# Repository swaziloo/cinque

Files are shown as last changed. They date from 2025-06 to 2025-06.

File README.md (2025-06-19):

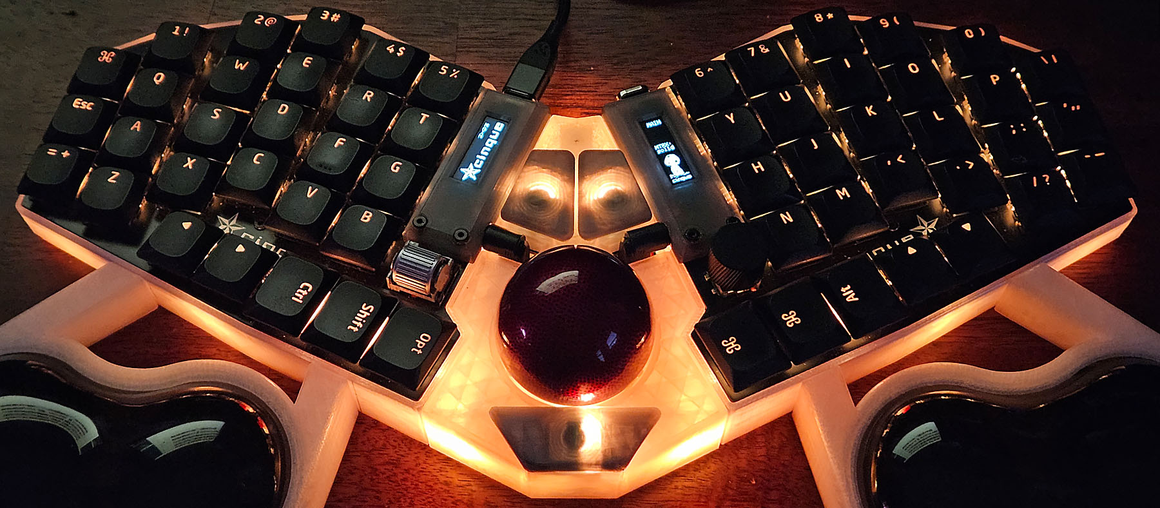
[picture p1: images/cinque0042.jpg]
cinique keyboard with trackball

# cinque 
### (\[ˈt͡ʃin.kwe\] or \[sĭngk\], your choice)
cinque is an open-source 56-key compact columnar staggered low-profile split 
mechanical keyboard and trackball with RGB lighting and rotary encoders
designed in [Ergogen](https://ergogen.xyz/)
laid out in [KiCad](https://www.kicad.org/)
with cases modeled in [FreeCAD](https://www.freecad.org/)
and driven by [QMK](https://qmk.fm/)
or [ZMK](https://zmk.dev/)
firmware. 
The project was inspired by (and borrows *heavily* from) the
[Corax](https://github.com/dnlbauer/corax-keyboard), 
[Atreus](https://atreus.technomancy.us/),
[Sofle](https://josefadamcik.github.io/SofleKeyboard/) and 
[Lily58](https://github.com/kata0510/Lily58) projects
and features footprints designed or inspired by [ceoloide](https://github.com/ceoloide/ergogen-footprints),
[infused-kim](https://github.com/infused-kim/kb_ergogen_fp),
and [dnlbauer](https://github.com/dnlbauer/corax-keyboard/tree/main/corax56/ergogen/footprints)

### Hardware
cinque is built around paired ProMicro controllers,
employing RP2040 (for wired, trackball, RGB, OLED)
or NRF52840 (for battery, Bluetooth, Nice!Nano).
Other MCUs and configurations are viable.
- **Switches:** Gateron KS-33 low-profile (MX stem) hot-swap
- **Rotary:** EC11 or Panasonic EVQWGD001 (horizontal) per side
- **Trackball:** PMW3389 module and Gateron KS-33 switches 
- **RGB:** SK6812 per-key and 3535 underglow lights (including trackball)
- **Display:** 0.91" I2C OLED or Nice!View (low-power) LCD (via custom footprint)

### Firmware
- [QMK](qmk/cinque/README.md) (for RP2040) including [my keymap](https://github.com/swaziloo/cinque/blob/main/qmk/cinque/CinqueKeymapQMK-01.pdf)
- [ZMK](https://github.com/swaziloo/cinque-zmk-config) (for NRF52840) including [my (very similar) keymap](https://github.com/swaziloo/cinque-zmk-config/blob/main/CinqueKeymapZMK-01.pdf)

Note that the firmware folders also include an [SVG template](https://github.com/swaziloo/cinque/blob/main/qmk/cinque/CinqueLayout01.svg) in case you want to lay out your own keymaps.

### [Build Guide](build.md)

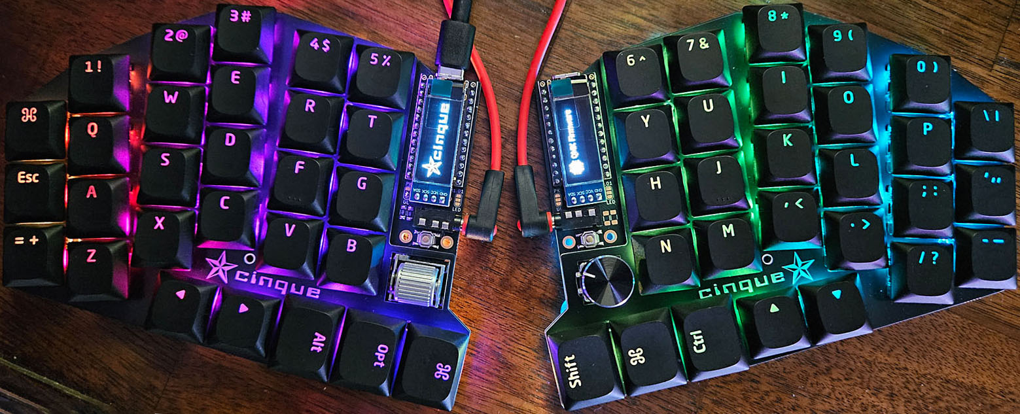
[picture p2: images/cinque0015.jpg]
cinque keyboard RGB Test


### [The Story](story.md)

### Versions
**1.0:**
The initial one-sided version (202410) is intended to enable a large number of possible features
and configurations.
- The EC11 switch plate cutout is too small and requires filing to accommodate the board connectors (fixed 1.1)
- NRF52840 P1.01 Nice!View CS pin option is untested
- I2C split communication is untested
- Right-side FPC (trackball) is untested

**1.1:**
(switch plate only at this time&mdash;202506)
Adds 1.25x8mm and 1.5x8mm side expansions to accommodate the EC11 connectors on the cutout.

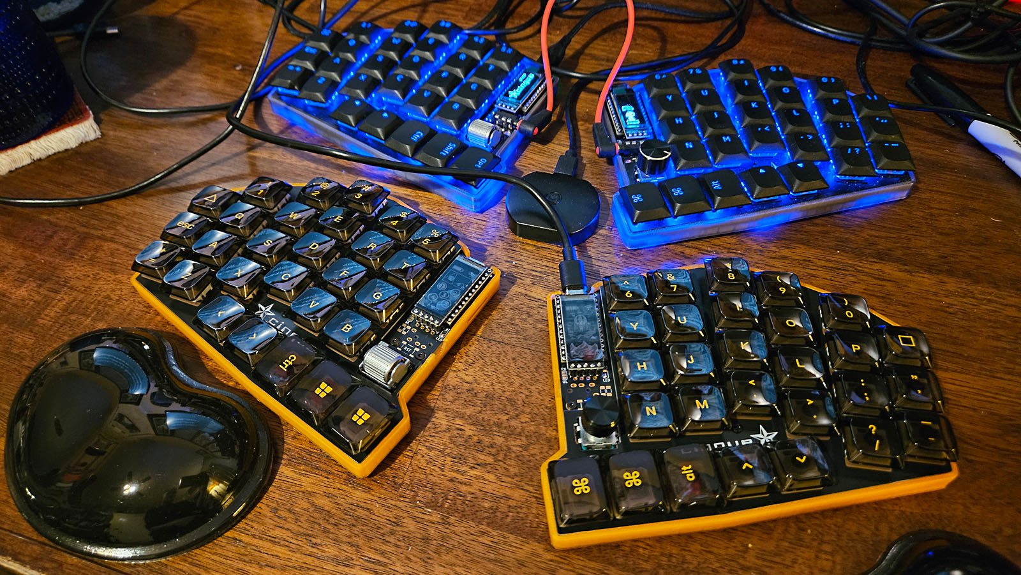
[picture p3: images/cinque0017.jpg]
cinque in minimal cases


### Future Development
- Move/change TRRS
- Large battery single side charge via Schottky diode(?) and shared power switch 
- Trackball with mouse (small) switches
- 34mm trackball (maybe)
- Kailh Choc, Cherry MX, (or other switch?) version
- Consider central (on board?) controller(s) with connected peripherals
- Find or design a horizontal encoder replacement for the Panasonic

cinque is licensed under an [MIT license](LICENSE).

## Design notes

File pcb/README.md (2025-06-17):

# cinque PCB 
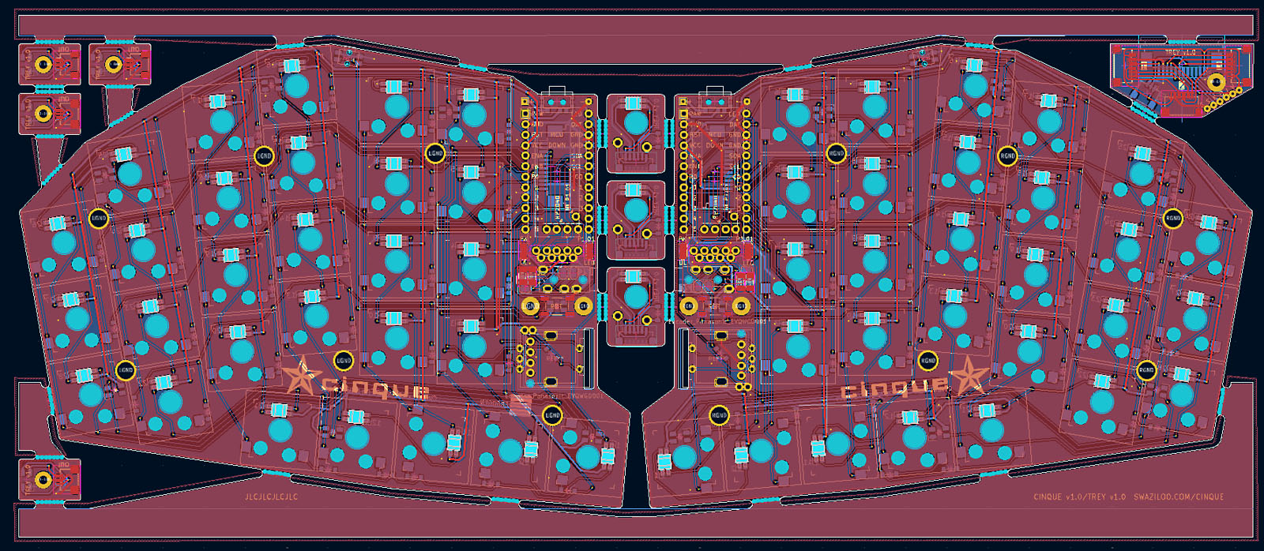
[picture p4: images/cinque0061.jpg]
cinque KiCad pcb


cinque was laid out by hand in [KiCad](https://www.kicad.org/) 8.0.8 from the Ergogen output files.

A single PCB panel will make a keyboard and trackball.

Gerber files were exported according to instructions from [JLCPCB](https://jlcpcb.com/help/article/how-to-generate-gerber-and-drill-files-in-kicad-8).

Let me know if something (footprint library?) doesn't come through, as I haven't previously exported KiCad files.

## cinque Switch Plate
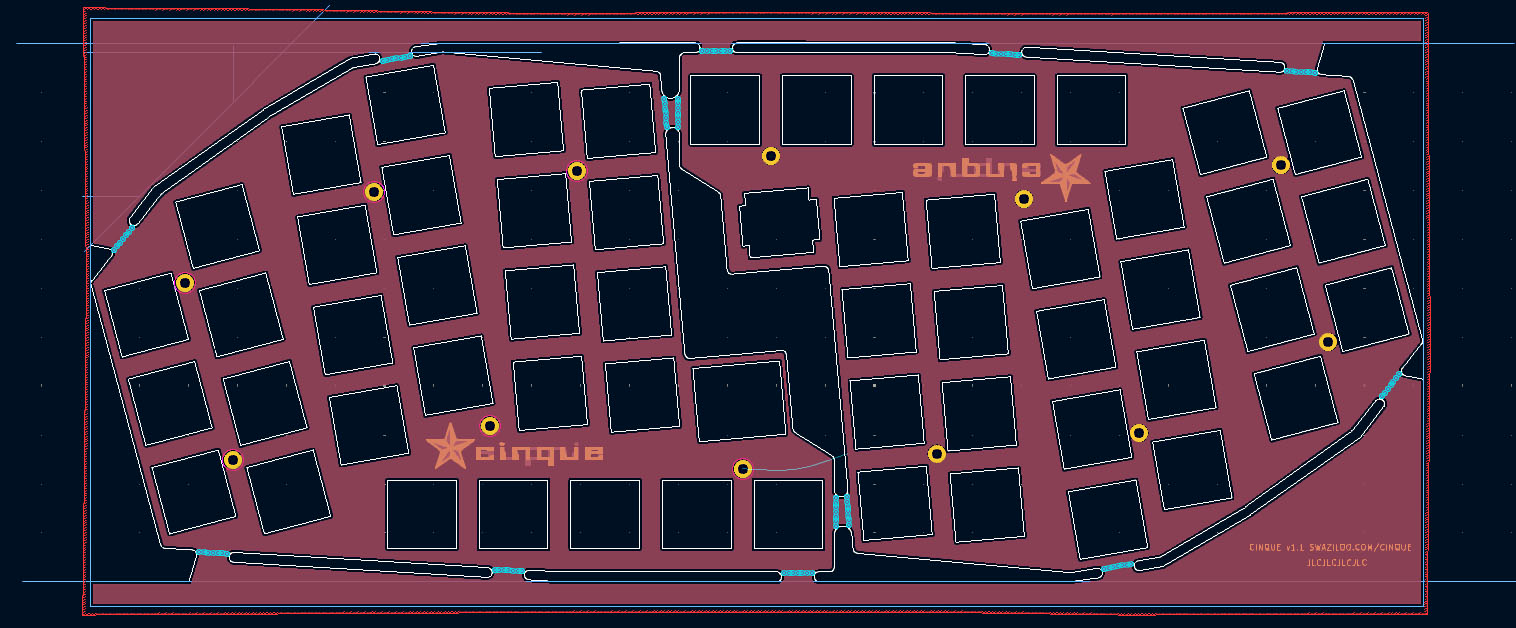
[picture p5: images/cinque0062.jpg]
cinque KiCad pcb

A single switch plate panel provides one EC11 and one EVQWGD001 cutout. These are reversible and can go on either side.

> **Note:** I have extra switch plates available with HASL finish.

## cinque Base Plate

There is no design or files for a base plate at this time (though one could be added.)

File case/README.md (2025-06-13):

# cinque Case Files
cinque cases are designed and drafted in [FreeCAD](https://www.freecad.org/) 1.0.1
with the intention of being produced on a 3D printer.
Add supports where needed.

stl files can be previewed, measured, and inspected in the [ONLINE 3D VIEWER](https://3dviewer.net/)

| | |
|---|---|
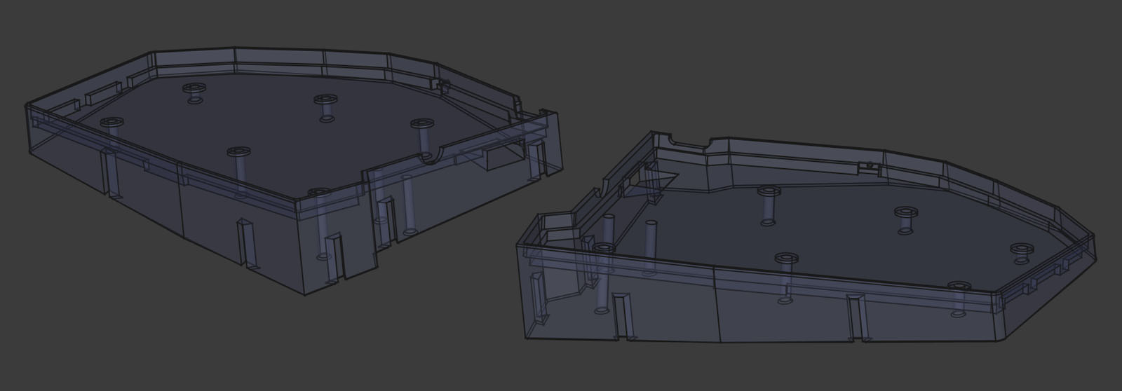
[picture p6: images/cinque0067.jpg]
cinque ergogen outlines
|  | v1.0 22mm negative tilt for wired boards. Print right-side up. |
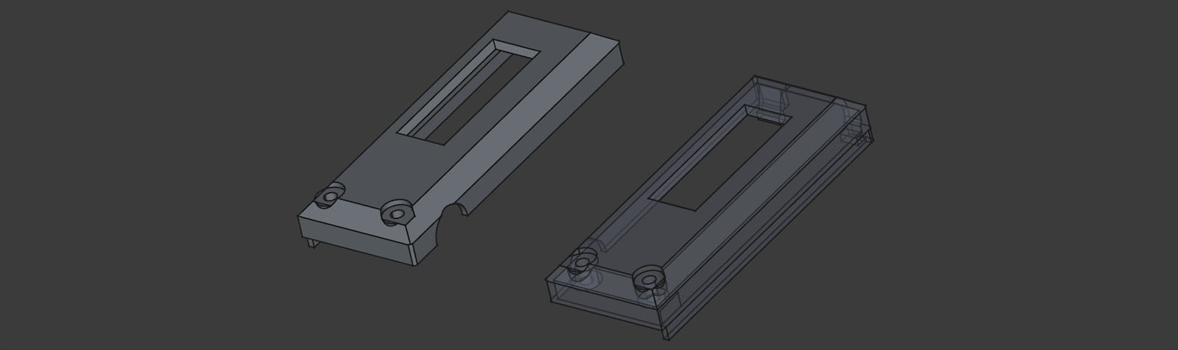
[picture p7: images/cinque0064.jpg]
cinque ergogen outlines
|  | v1.0 covers for OLED displays (use 5mm m2 standoffs). Print upside-down. |
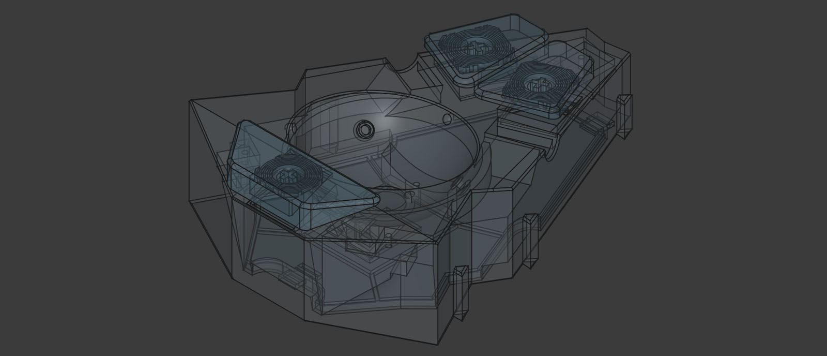
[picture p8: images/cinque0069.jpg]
cinque ergogen outlines
|  | v1.0 trackball with keycaps and base cover. Print housing upside-down with supports. Print keycaps with the stem turned 45-degrees upwards and enough supports to handle the keys tilted on their edge. Print cover right-side up with suports for tabs. |
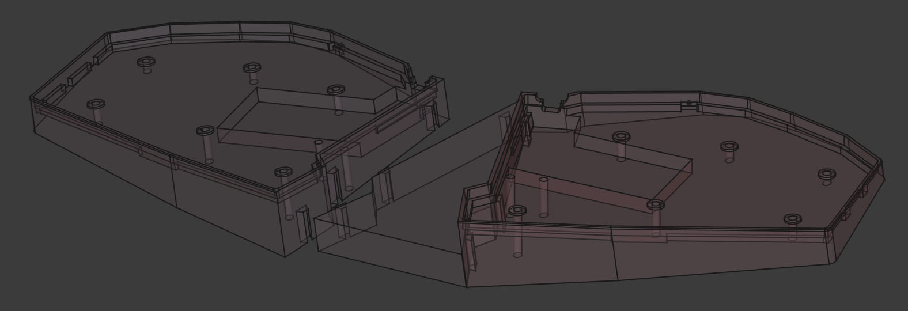
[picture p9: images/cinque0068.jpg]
cinque ergogen outlines
|  | v1.0 22mm negative tilt for wireless boards. Print right-side up. Includes minimal spacer for v1.0 22mm negative tilt boards. |
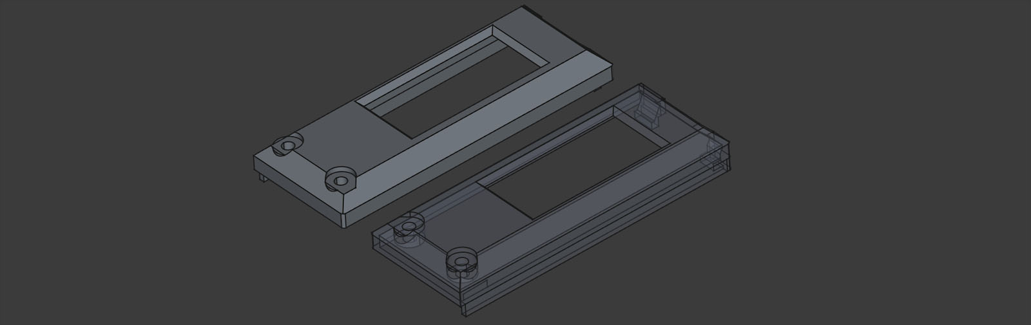
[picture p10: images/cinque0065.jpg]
cinque ergogen outlines
|  | v1.0 covers for Nice!View displays (use 5mm m2 standoffs). Print upside-down. Take care snapping clips under the top of the ProMicro. |
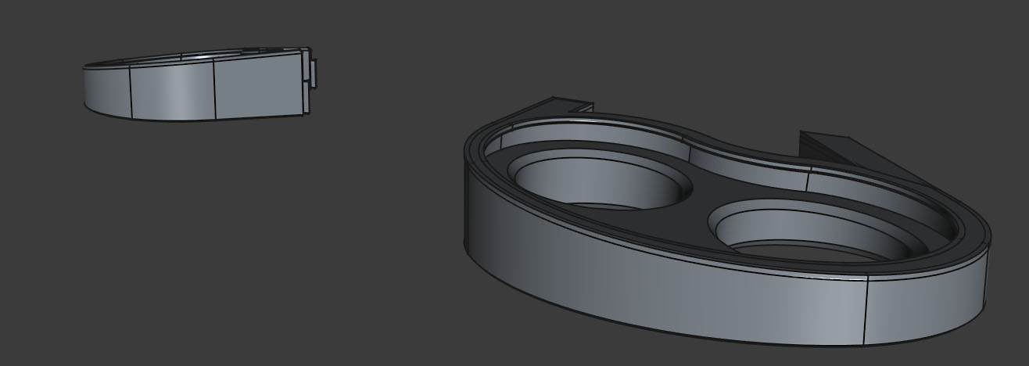
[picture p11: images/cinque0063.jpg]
cinque ergogen outlines
|  | v1.0 7x11cm jelly wrist rest holders. Print with supports. |
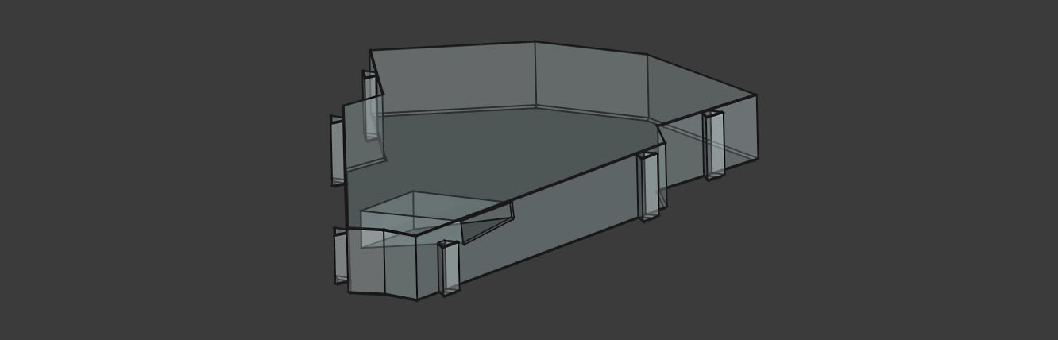
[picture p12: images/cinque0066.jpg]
cinque ergogen outlines
|  | v1.0 trackball-sized spacer with ribbon cutout. |

I do not have a current minimalist "flat" case but could easily add one on request.

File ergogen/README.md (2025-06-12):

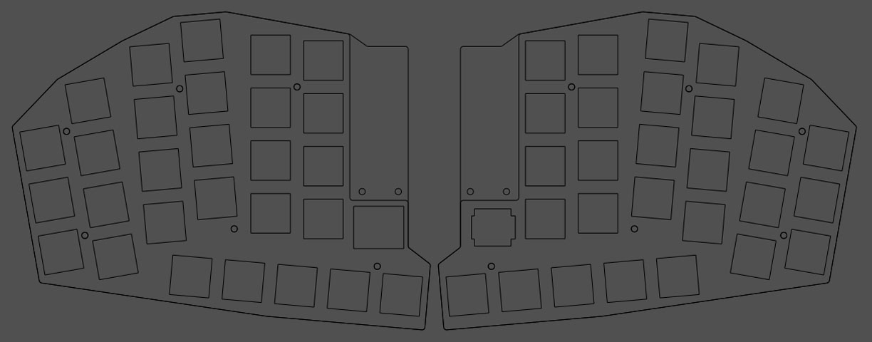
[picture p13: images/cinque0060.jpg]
cinque ergogen outlines

# cinque Ergogen files
cinque was built on [Ergogen](https://ergogen.xyz/) 4.1.0 using footprints from
[ceoloide](https://github.com/ceoloide/ergogen-footprints) and
[dnlbauer](https://github.com/dnlbauer/corax-keyboard/tree/main/corax56/ergogen/footprints).

In order to build the Ergogen assets you will need to:
- Install Ergogen locally
- Copy this folder into your Ergogen file structure and rename it `cinque`
- In the `cinque/footprints` subfolder, check out (or copy) both ceoloide and dnlbauer (under `corax`) footprint files
- From the main Ergogen directory execute `src/cli.js cinque` (or equivalent)
- Assets can be found in the `output` folder

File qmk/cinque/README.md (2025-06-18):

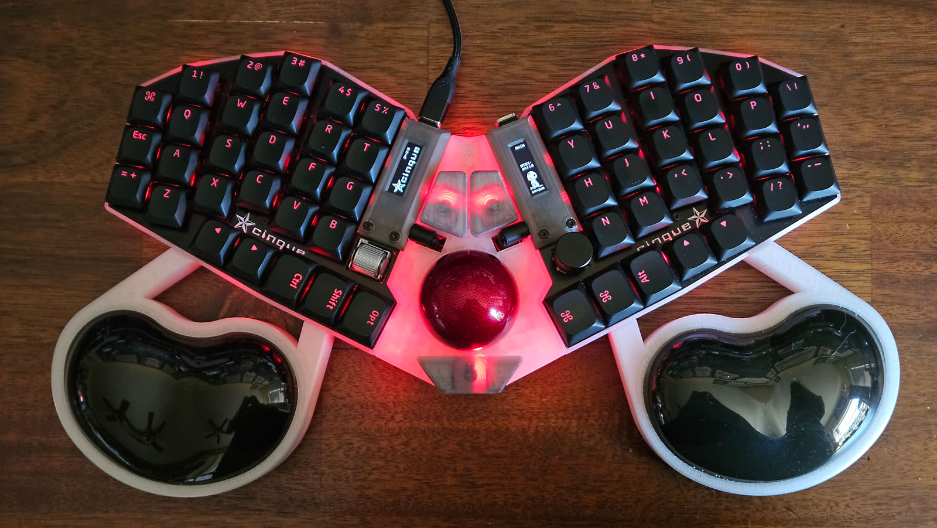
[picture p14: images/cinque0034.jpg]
cinque

# cinque
*cinque is an open-source 56-key compact columnar staggered low-profile split mechanical keyboard and trackball with RGB matrix lighting and rotary encoders*

* Keyboard Maintainer: [swaziloo](https://github.com/swaziloo)
* Hardware Supported: cinque v1 (wired) with RP2040 ProMicro MCU via chibios
  * Note that the cinque likely works with other ProMicro controllers
* Hardware Availability: [github/swaziloo/cinque](https://github.com/swaziloo/cinque)
* Use [ZMK](https://github.com/swaziloo/cinque-zmk-config) firmware for Bluetooth (NRF52840) builds

*Note that it is recommend to flash your RP2040 ProMicro before soldering it to the board, as the default bootloader may not support double-tap flashing.*

See the [build environment setup](https://docs.qmk.fm/#/getting_started_build_tools) and the [make instructions](https://docs.qmk.fm/#/getting_started_make_guide) for more information. Brand new to QMK? Start with our [Complete Newbs Guide](https://docs.qmk.fm/#/newbs).

## Building the Firmware
* Check out the QMK [qmk firmware](https://github.com/qmk/qmk_firmware) project and configure your environment to compile it.
  * For Windows I recommend [git bash](https://gitforwindows.org/) and the [QMK MSYS](https://msys.qmk.fm/) shell.
* From within your `qmk_firmware` project check out the submodules and run qmk setup: 
```
git submodule update --init --recursive
qmk setup
```

* *If using the trackball*, modify the following lines in the `platforms/chibios/boards/GENERIC_PROMICRO_RP2040/configs/mcuconf.h` file to enable the SPI1 driver:
```
-#define RP_SPI_USE_SPI0                     TRUE
-#define RP_SPI_USE_SPI1                     FALSE
+#define RP_SPI_USE_SPI0                     FALSE
+#define RP_SPI_USE_SPI1                     TRUE
```
* Copy this folder (cinque) to the `qmk_firmware\keyboards` folder.
* To build the firmware for the cinque with RGB support, enter this command in your QMK MSYS terminal from the `qmk_firmware` folder:
```
qmk compile -kb cinque/rp2040rgb -km default
```
* To build the firmware for cinque with RGB and trackball support, enter this command in your QMK MSYS terminal from the `qmk_firmware` folder:
```
qmk compile -kb cinque/rp2040rgbtrackball -km default
```
* The `.uf2` firmware file should be linked and copied to your `qmk_firmware` folder.

## Flashing
Double tap the reset (RST) button on your MCU or board. 
The RP2040 will connect as a USB drive into which you drop the `.uf2` file you just built.
The RP2040 will reconnect as a keyboard once it installs the firmware. Connect and flash both MCUs.

## Bootloader
If the double-tap reset doesn't mount the RP2040 as a drive you may need to hold the physical BOOT button on the front of the MCU while connecting it to your PC.

## Kodama
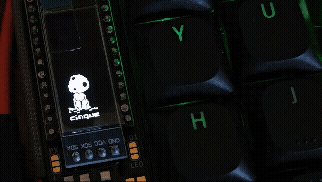
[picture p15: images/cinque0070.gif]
cinque kodama


If you're here for the Kodama, the `kodama.c` and `kodama.h` files should be portable. You'll need 6 lines for the animation which you configure at the top of the `kodama.c` file. Then call `render_animated_kodama();` in your `oled_task_user()` function for the correct OLED.

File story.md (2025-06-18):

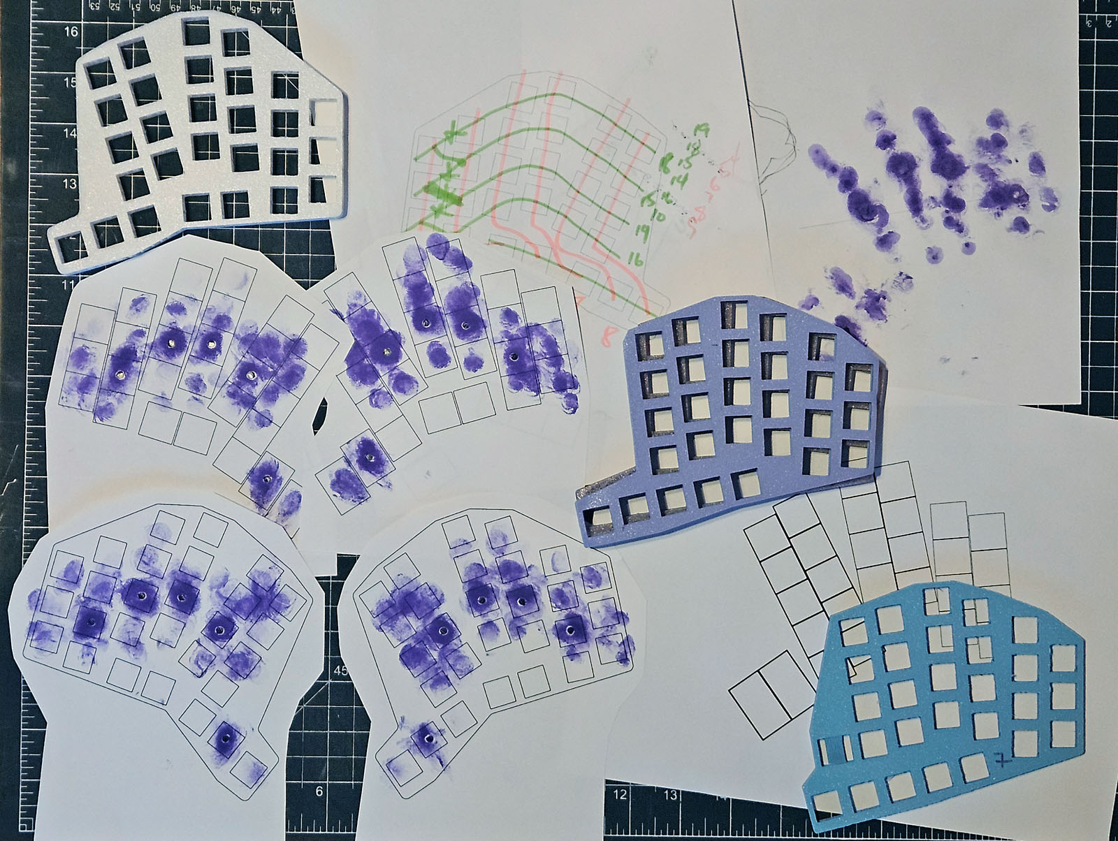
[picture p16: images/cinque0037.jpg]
cinque hand study
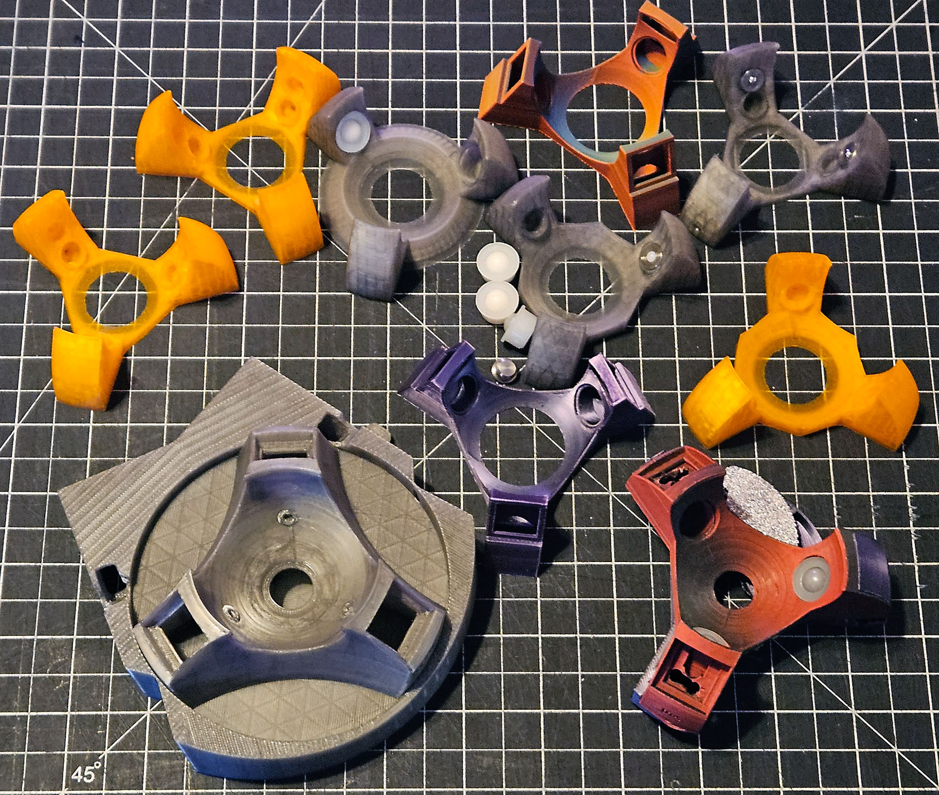
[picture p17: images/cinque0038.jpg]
cinque hand study
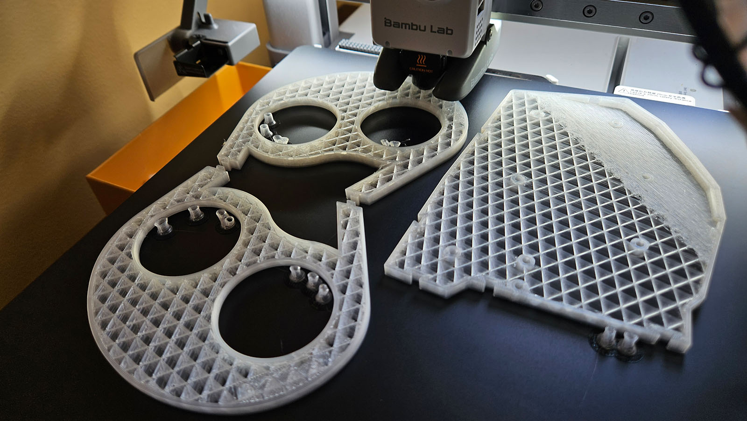
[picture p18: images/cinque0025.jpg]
cinque hand study
|  |  |  |
|---|---|---|
# The Story
I've used columnar and mechanical keyboards for years.
Upon discovering [Ergogen](https://ergogen.xyz/) 
and the [Flat Foot Fox](https://flatfootfox.com/) tutorials 
I felt compelled to measure the angles, motion, range, and tilt of my hands.
I used ink and paper to create heat maps from which I drew overlays in Ergogen.
From Ergogen output I built 3D-printed switch holders.
I iterated through seven versions to refine the shape of cinque.

I wanted a compact upgrade akin to my [Atreus](https://atreus.technomancy.us/) keyboard,
since I found it too limiting for a software development daily driver.
My goals were comfort, compact, and an integrated trackball.

My efforts moved to learning KiCad and figuring out how to trace a PCB 
(I would ultimately lay out the complete PCB three times).
I was convinced by a friend that I *must* include matrix RGB lighting.
Originally I planned a reversible board, but separate halves made the FPC trackball connector viable.
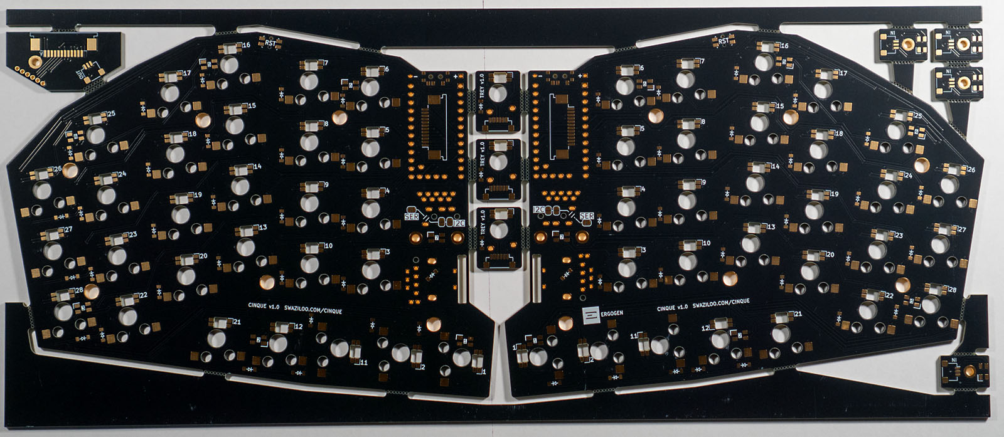
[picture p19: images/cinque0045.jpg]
single sided cinque made everything fit


While wrapping up the PCB layout I began testing the trackball shape and bearing options
(and ended up merely verifying [wiwilwi's excellent post on KBD news](https://kbd.news/Trackball-bearing-comparison-1757.html)).
I wanted a trackball in the middle of the keyboard,
large (originally a 57.25mm billiard ball),
and to drive it via the extra pins a RP2040 ProMicro would provide.
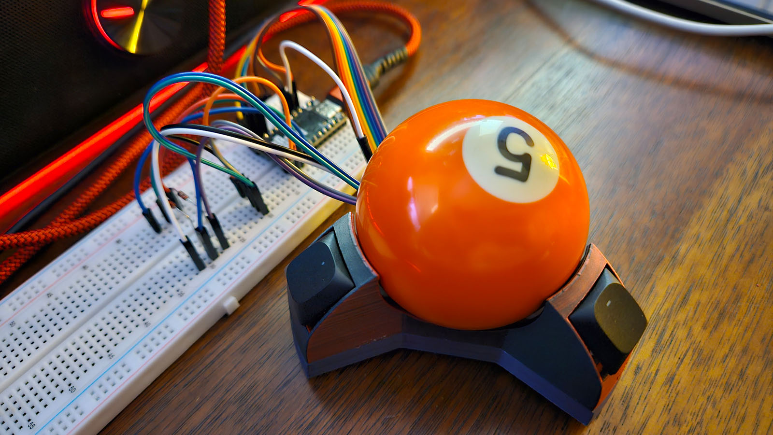
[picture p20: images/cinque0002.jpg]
working trey trackball test


The PCBs would include small breakout boards to mount the switches and lights 
and string it together with JST connectors to support experimenting with the fundamentals of the trackball.

Once I got the PCBs in hand and the first keyboard up and running the job switched to case design.
I purchased a Bambu Lab A1 to facilitate the iterations that refining each component required.

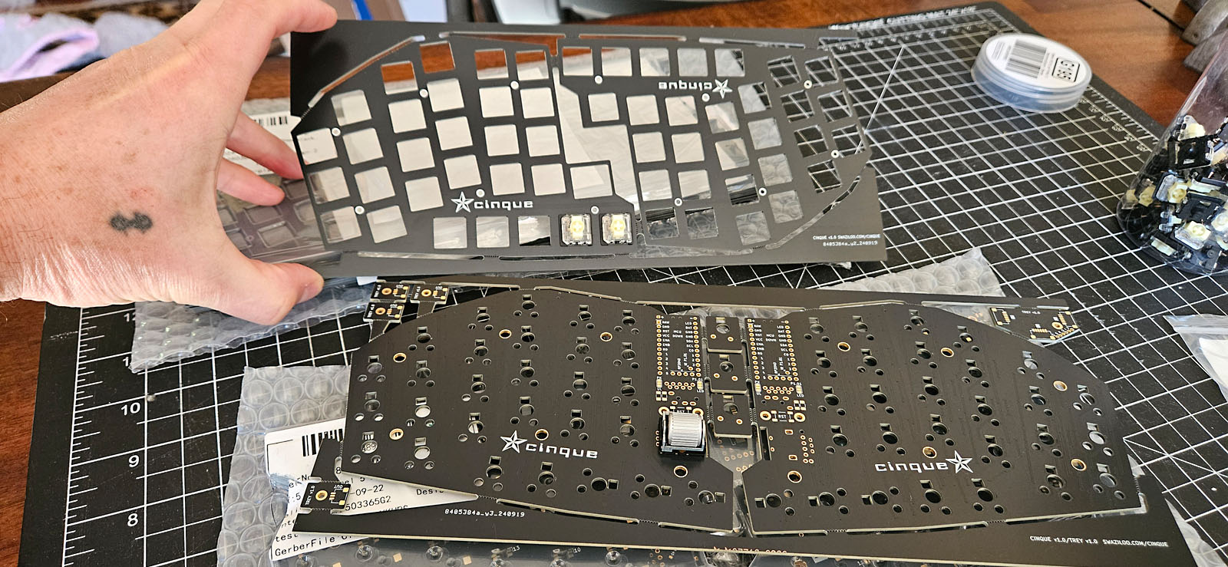
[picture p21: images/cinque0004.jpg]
cinque PCBs received
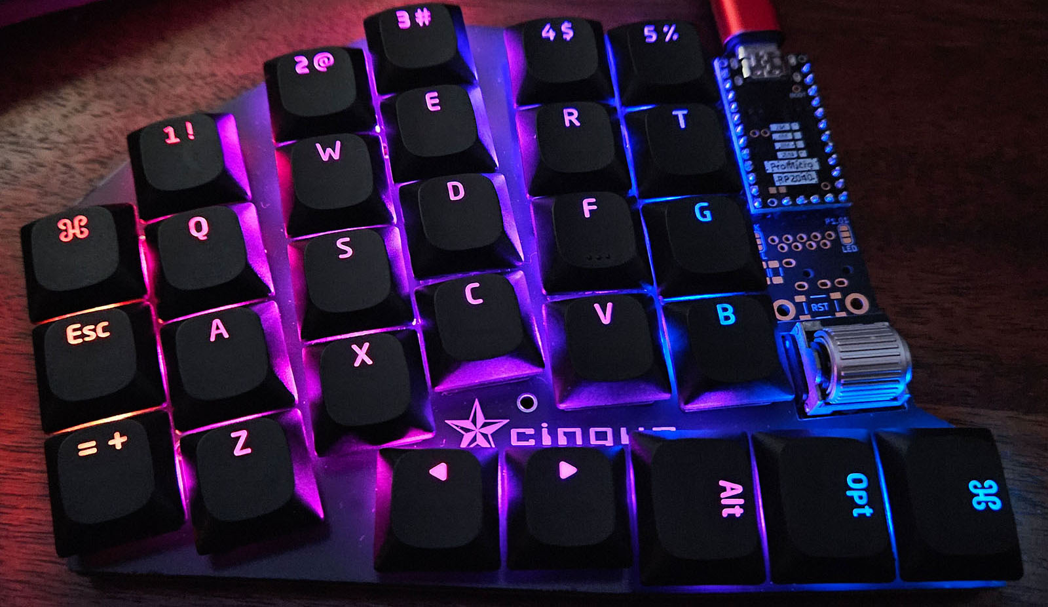
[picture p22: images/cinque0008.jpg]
first cinque alive
|  |  |
|---|---|
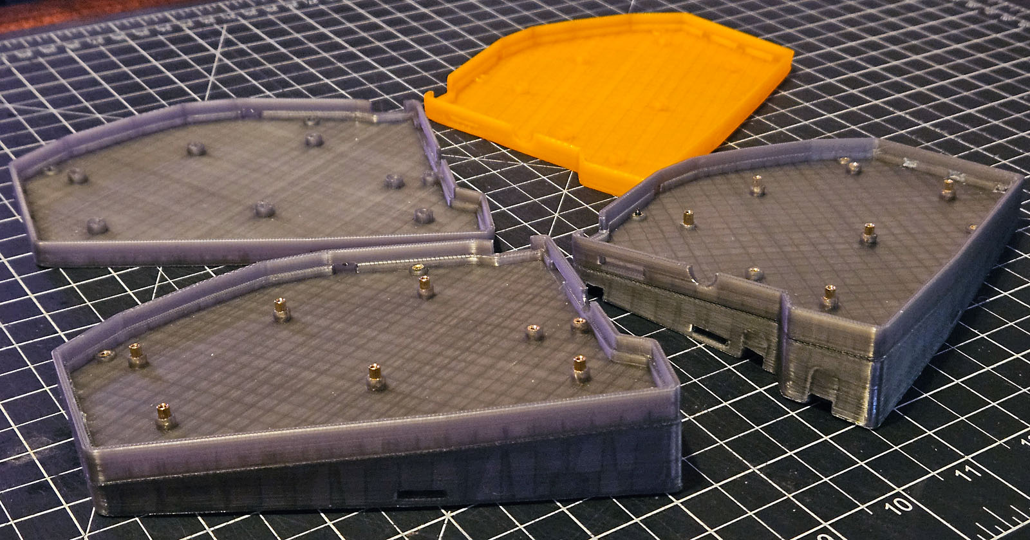
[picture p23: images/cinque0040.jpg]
cinque flat case plus riser
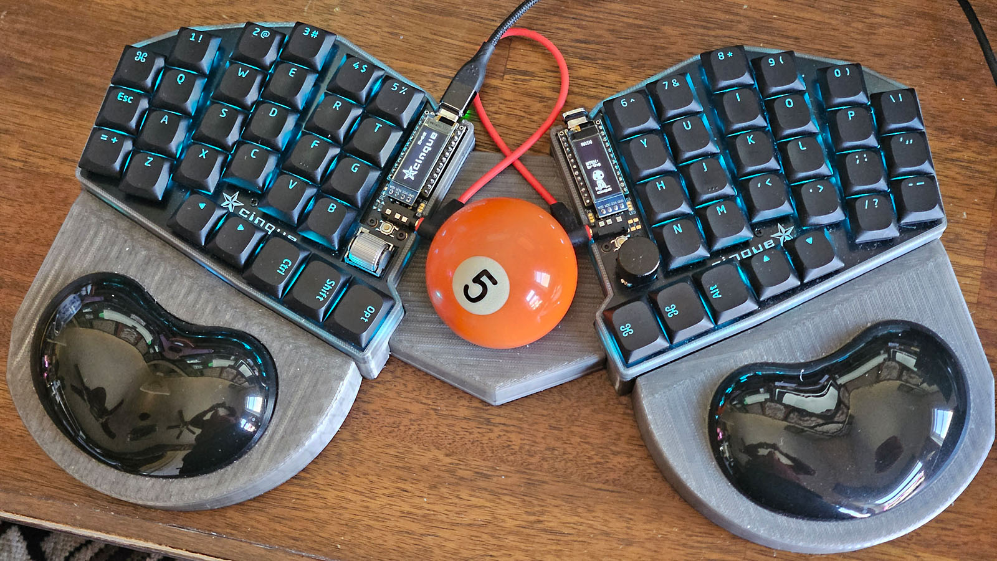
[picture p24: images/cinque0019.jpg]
first wrist rest and billiard placeholder
|  |  |
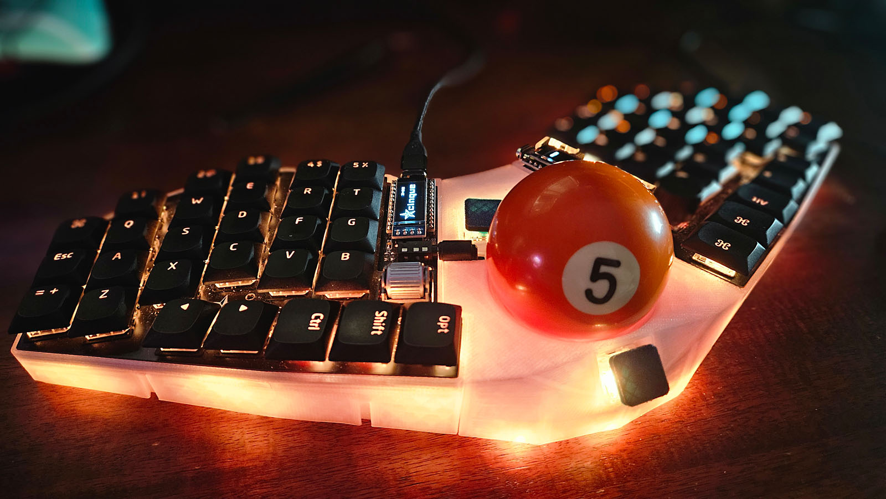
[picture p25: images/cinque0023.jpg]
first integrated trackball
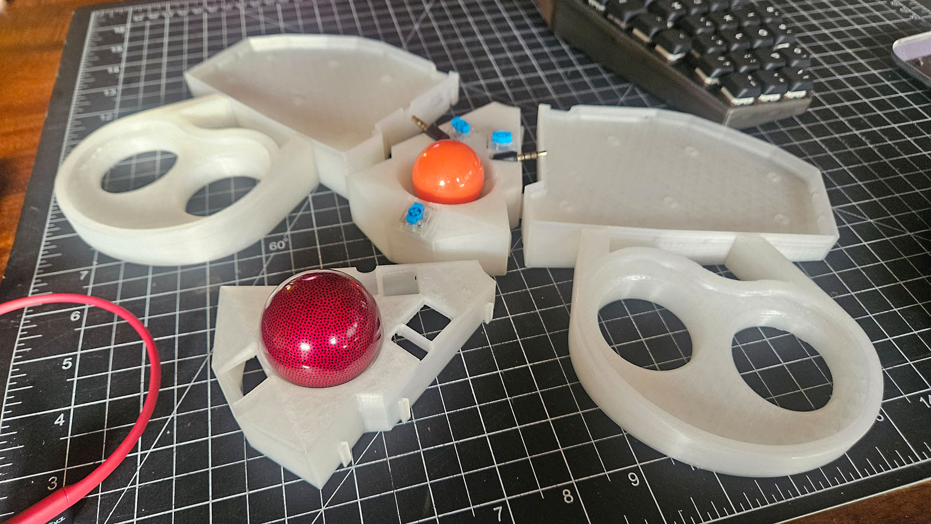
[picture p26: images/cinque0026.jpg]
cinque 1.0 case with 44mm trackball housings
|   |  |

Ultimately I ditched the billiard ball,
as it tracked poorly and pushed the keyboard halves apart.

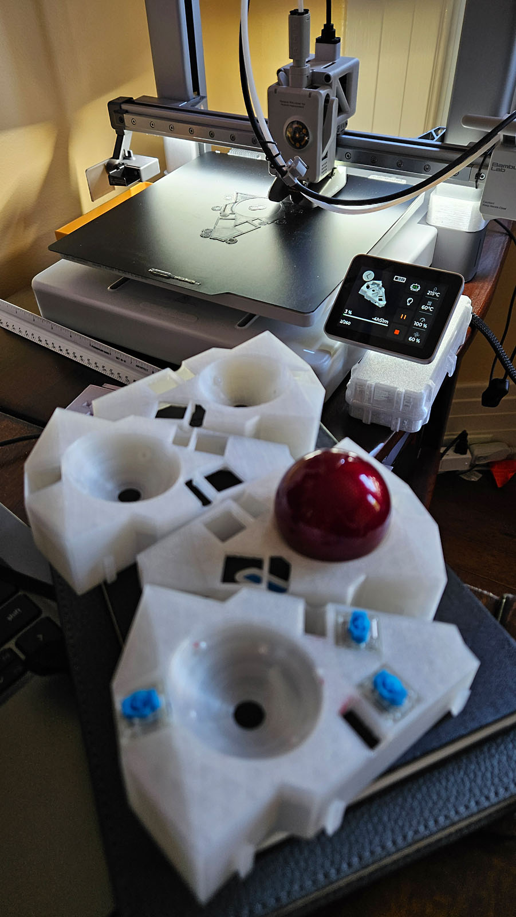
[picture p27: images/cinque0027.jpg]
cinque wireless
| The trackball housing required a good deal of incremental refinement. There is a lot going on in a relatively small space. |  |
|---|---|

I've also built the wireless/Nice!View "portable" board with a spacer. 
There's room for a large lipo battery beneath each half.

| cinque wireless | cinque wireless |
|---|---|

And here's where things stand in June 2025:

| cinque | cinque |
|---|---|
| cinque | cinque |

My sole regret is the TRRS location, though I have been able to manage with some tight tolerances around the trackball.
A future revision may see a change in connector type to support relocation.
Need to give that a think.

Thanks for taking a look. 
Yes, I'm writing all this on the cinque.
Gateron KS-33 Banana switches are fantastic.
It is my daily driver for work and play.

I appreciate any comments, suggestions, or ideas.

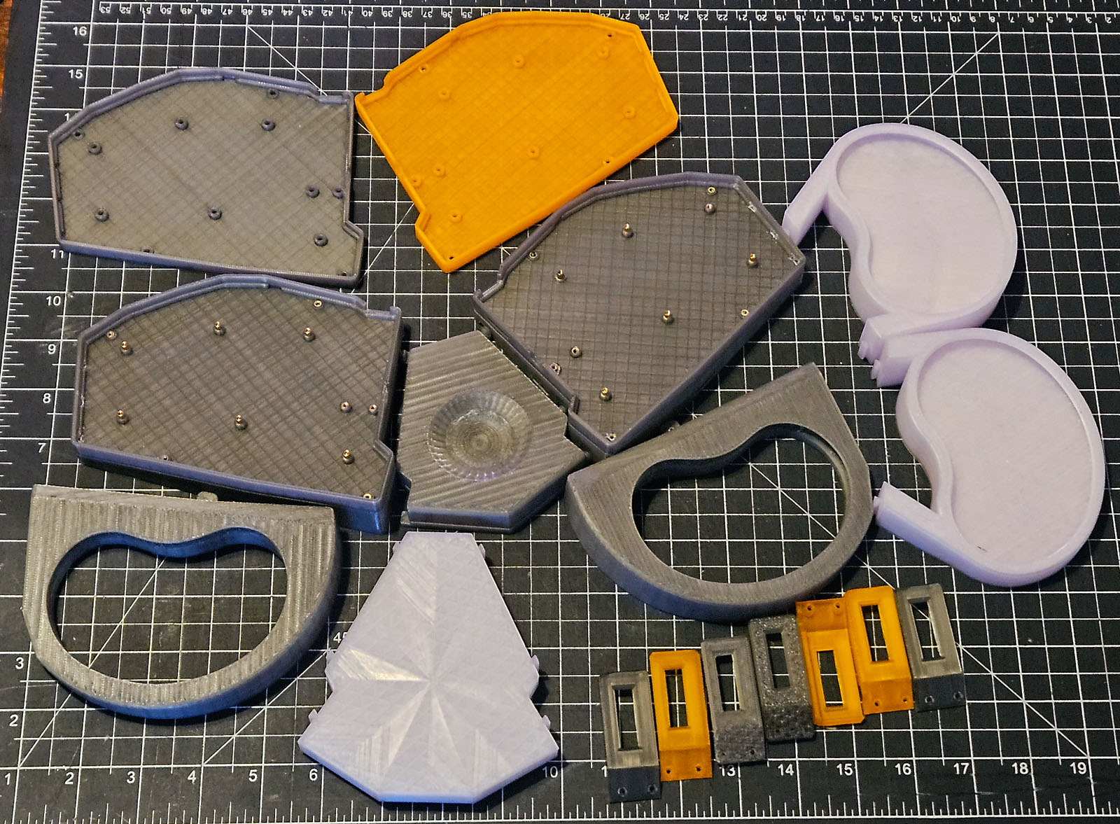
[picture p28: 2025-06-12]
images/cinque0039.jpg

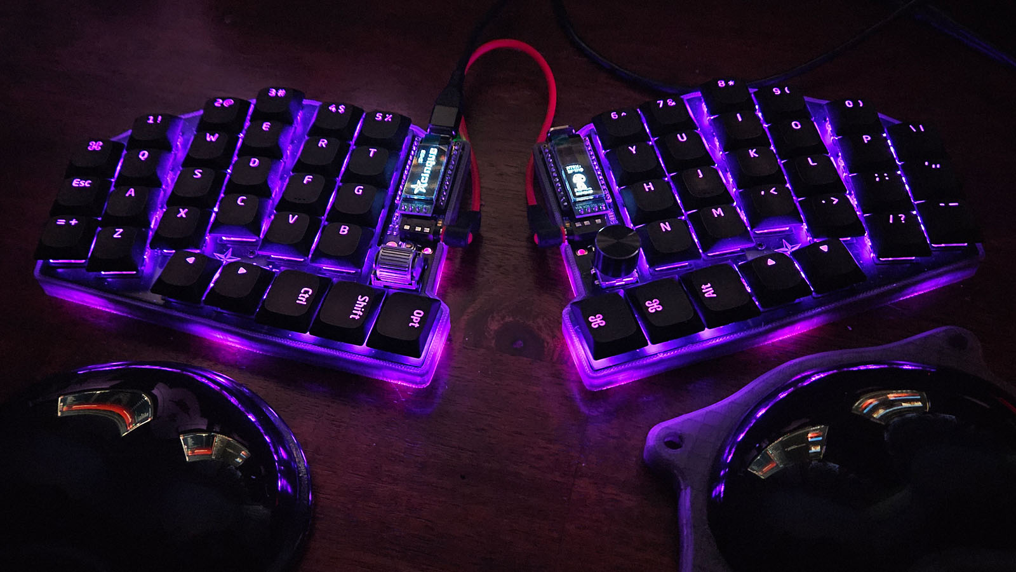
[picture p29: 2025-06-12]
images/cinque0016.jpg

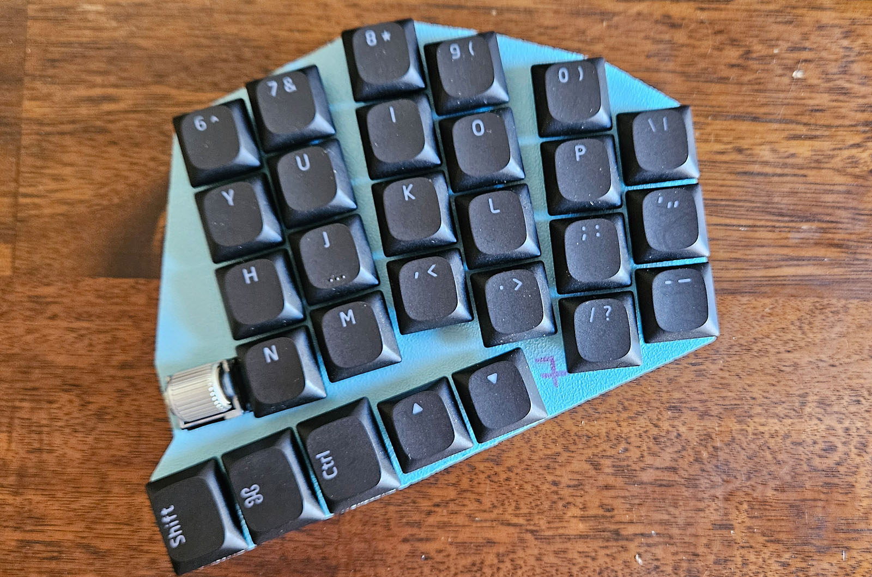
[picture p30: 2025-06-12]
images/cinque0003.jpg

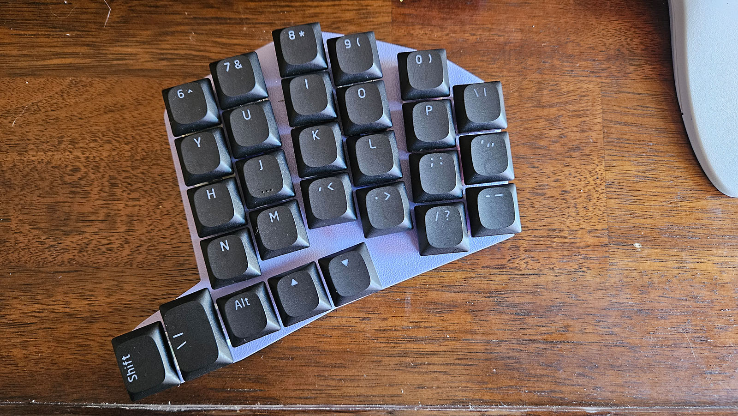
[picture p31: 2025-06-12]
images/cinque0001.jpg

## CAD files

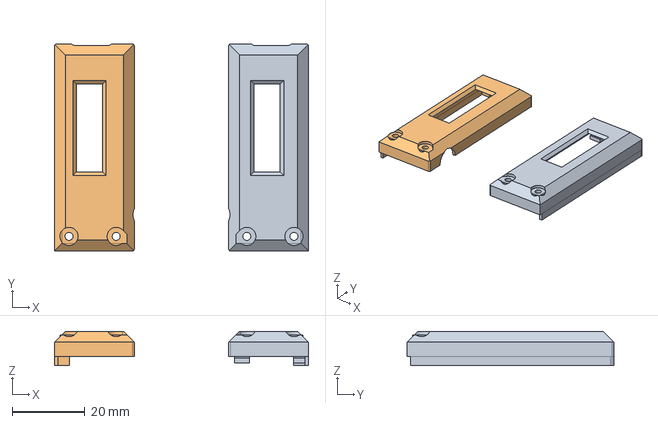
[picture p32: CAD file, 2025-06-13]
case/cinque-1.0-cover-OLED.FCStd
70.0 x 57.0 x 9.50 mm

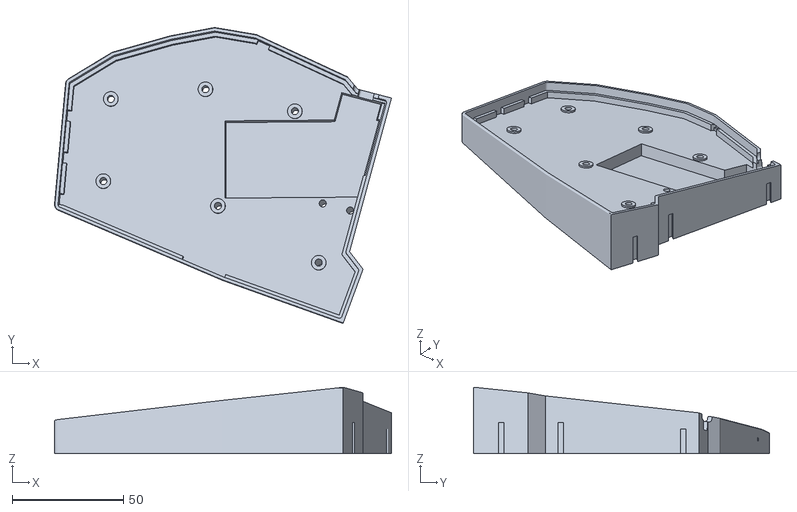
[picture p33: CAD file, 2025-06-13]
case/stl/cinque-1.0-case-battery-left.stl
151.5 x 133.1 x 29.9

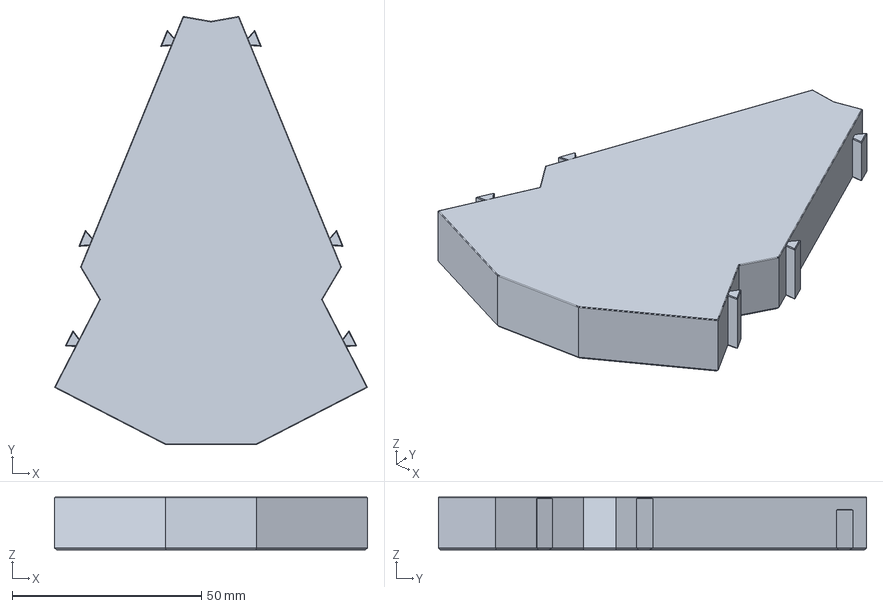
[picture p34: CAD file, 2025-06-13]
case/cinque-1.0-connector-t.FCStd
82.7 x 113.1 x 14.0 mm

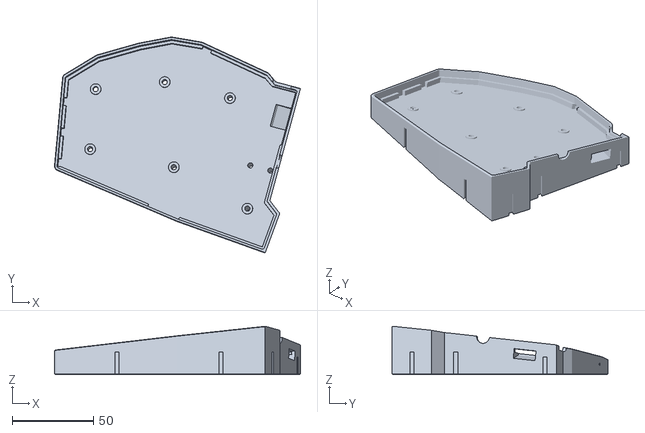
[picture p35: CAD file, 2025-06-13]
case/stl/cinque-1.0-case-wired-left.stl
151.5 x 133.1 x 29.9

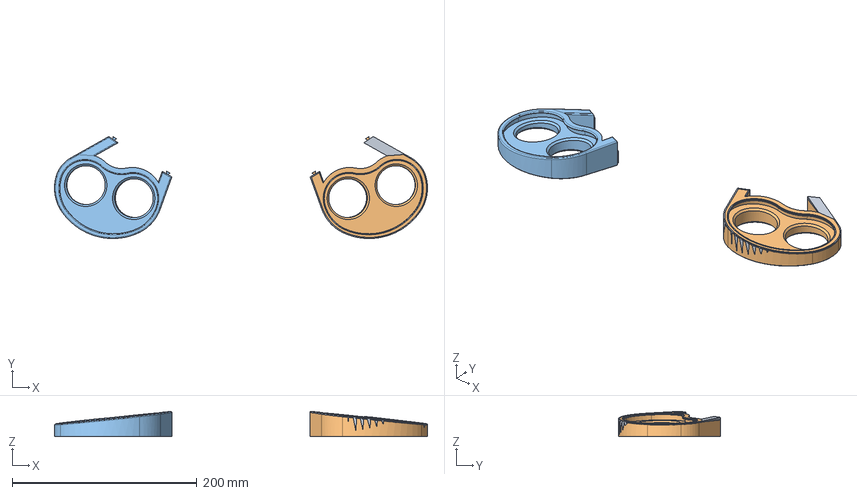
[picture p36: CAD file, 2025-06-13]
case/cinque-1.0-wrist-rest.FCStd
403.3 x 110.3 x 27.5 mm
Slice
Fillet (Mirror #1)

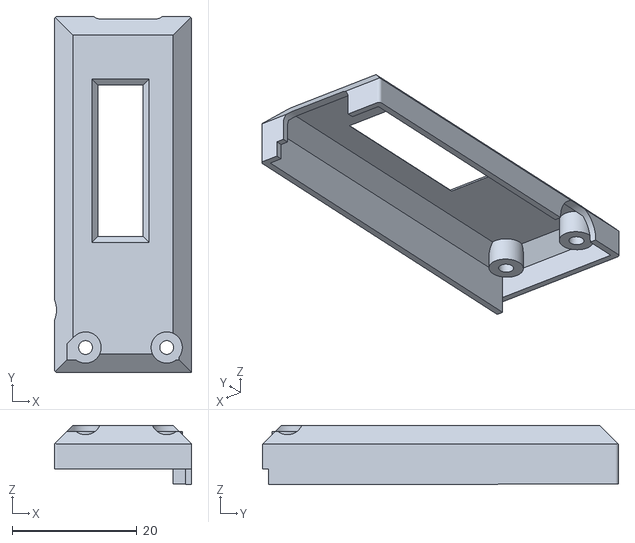
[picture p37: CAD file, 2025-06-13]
case/stl/cinque-1.0-display-cover-OLED-right.stl
22.0 x 57.0 x 9.50

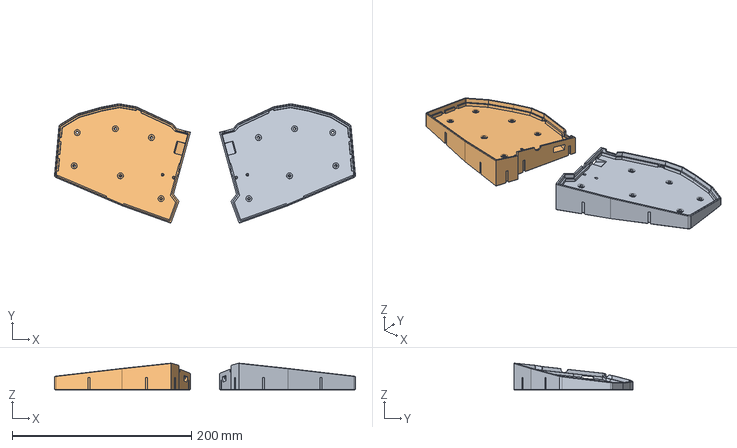
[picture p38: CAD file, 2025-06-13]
case/cinque-1.0-case-wired.FCStd
335.5 x 133.1 x 29.9 mm
Main Case
Chamfer002 (Mirror #1)

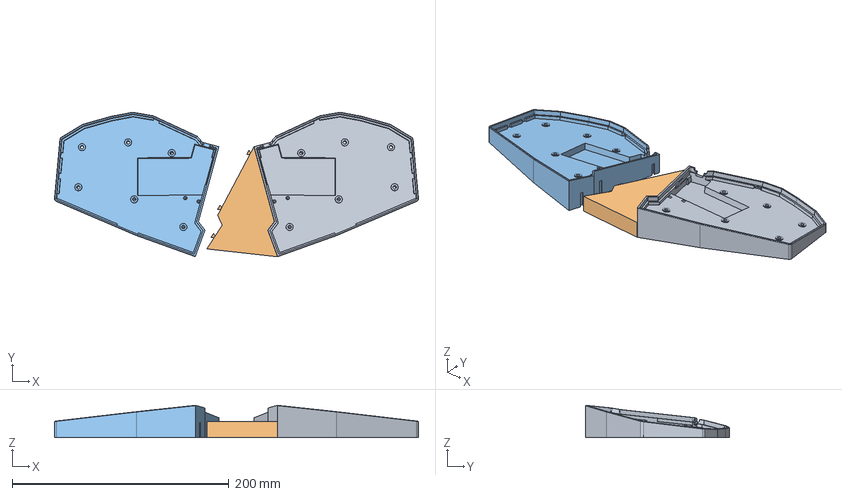
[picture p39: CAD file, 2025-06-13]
case/cinque-1.0-case-battery.FCStd
335.5 x 133.2 x 29.9 mm
Main Case
Coupler
Pocket012 (Mirror #1)

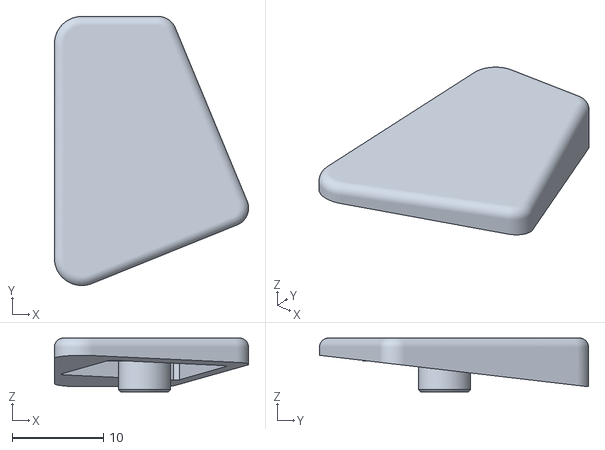
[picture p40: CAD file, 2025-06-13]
case/stl/cinque-1.0-trackball-keycap-right.stl
21.2 x 29.4 x 5.90

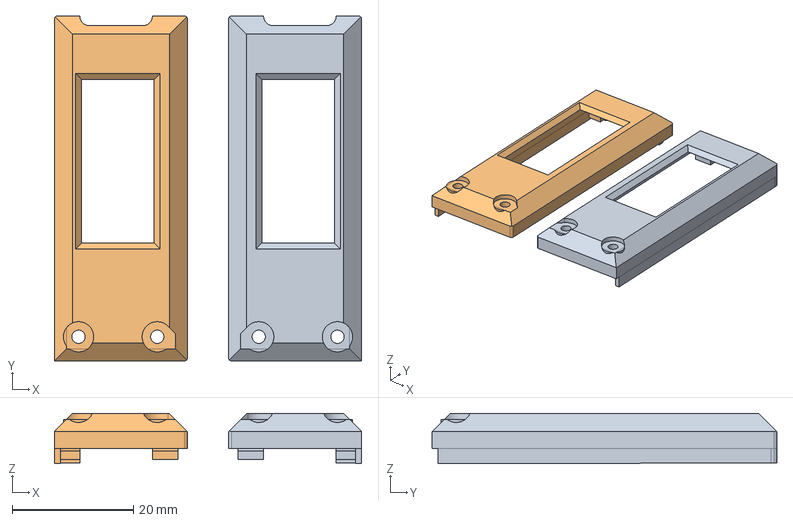
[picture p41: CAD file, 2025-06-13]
case/cinque-1.0-cover-Nice.FCStd
50.8 x 57.0 x 8.30 mm
Pad005 (Mirror #1)

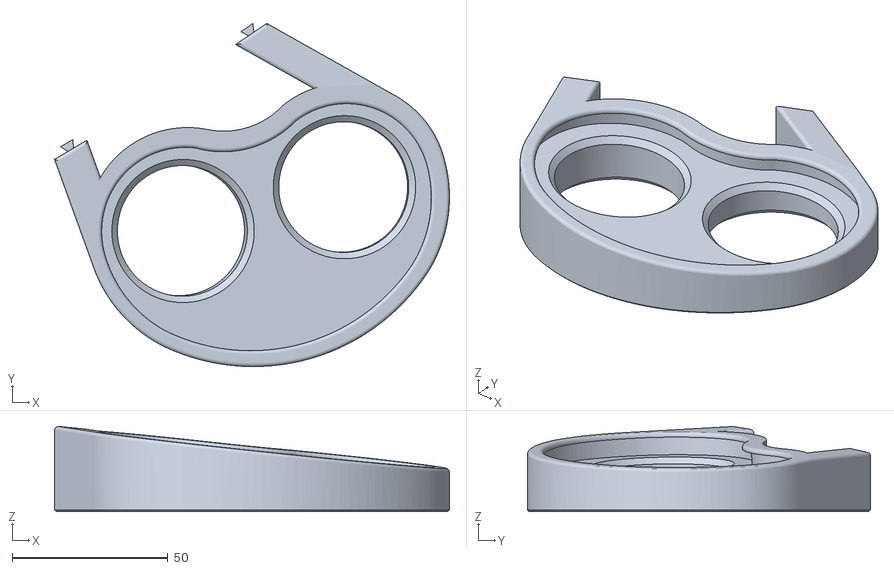
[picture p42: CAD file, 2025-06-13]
case/stl/cinque-1.0-wrist-rest-right.stl
127.0 x 110.3 x 27.3

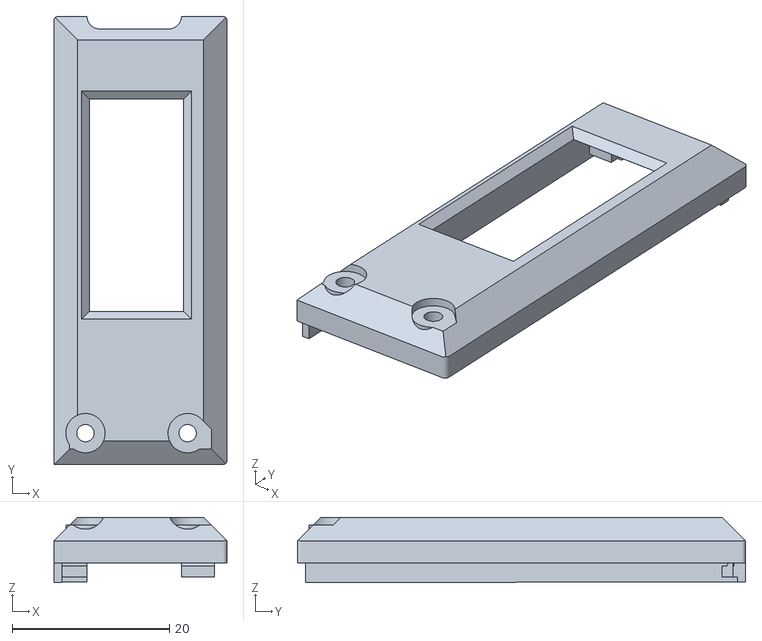
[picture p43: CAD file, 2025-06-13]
case/stl/cinque-1.0-display-cover-Nice-left.stl
22.0 x 57.0 x 8.30

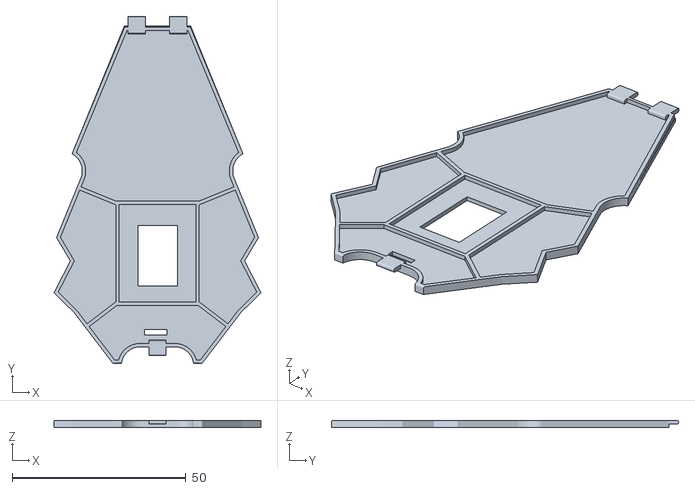
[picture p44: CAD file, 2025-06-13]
case/stl/cinque-1.0-trackball-base.stl
59.5 x 99.9 x 2.00

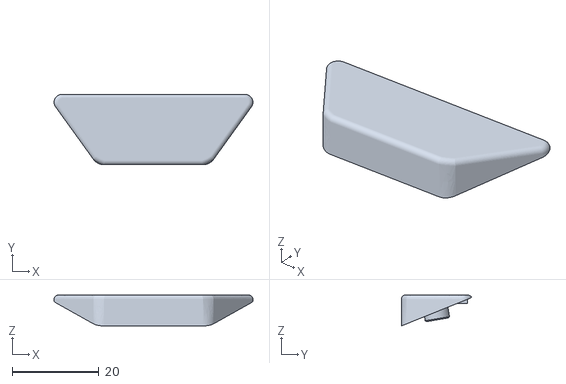
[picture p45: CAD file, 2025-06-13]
case/stl/cinque-1.0-trackball-keycap-front.stl
46.0 x 16.3 x 7.15

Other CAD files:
case/stl/cinque-1.0-case-wired-right.stl
case/stl/cinque-1.0-display-cover-OLED-left.stl
case/stl/cinque-1.0-connector-b.stl
case/stl/cinque-1.0-case-battery-right.stl
case/stl/cinque-1.0-connector-t.stl
case/stl/cinque-1.0-display-cover-Nice-right.stl
case/stl/cinque-1.0-trackball-keycap-left.stl
case/stl/cinque-1.0-wrist-rest-left.stl

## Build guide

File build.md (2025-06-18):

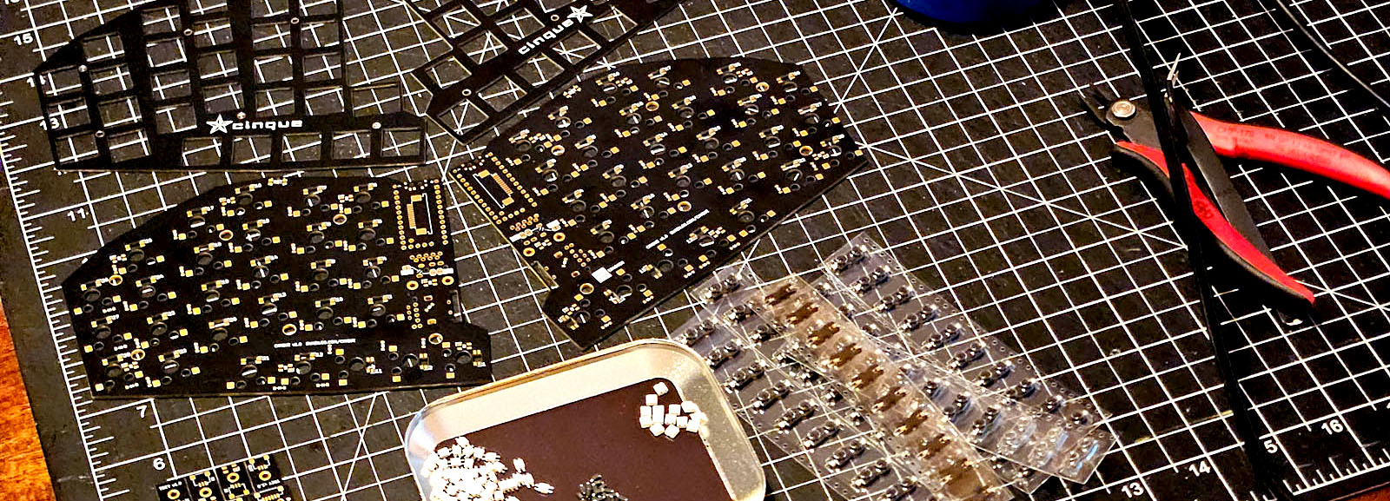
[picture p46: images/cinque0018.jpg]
cinque keyboard build parts

# Building cinque
> **Tip:** This guide assumes familiarity with custom keyboard builds.
> For information on building this family of keyboard, the detailed build guide for the
> [Sofle Choc](https://brianlow.notion.site/Sofle-Choc-Build-Guide-c4bbbaece6e746f7a5956842af567e79)
> and the build guides for 
> the [Lily58 Pro](https://github.com/kata0510/Lily58/blob/master/Pro/Doc/buildguide_en.md)
> the [Sofle RGB](https://josefadamcik.github.io/SofleKeyboard/build_guide_rgb.html)
> and [Corax](https://github.com/dnlbauer/corax-keyboard/blob/main/docs/BuildGuide.md)
> will provide some fundamental instructions.

The first step is to determine configuration and options and ensure that the ProMicro and power scheme will support them. 
I've built two configurations so far: RP2040 ProMicro (wired) with full RGB/Trackball/OLED (similar to Sofle Choc) using QMK firmware
and NRF52840 ProMicro with Nice!View and battery power (similar to Corax) using ZMK firmware.

> **Note:** I have extra v1.0 switch plates with HASL finish. Contact me if interested.

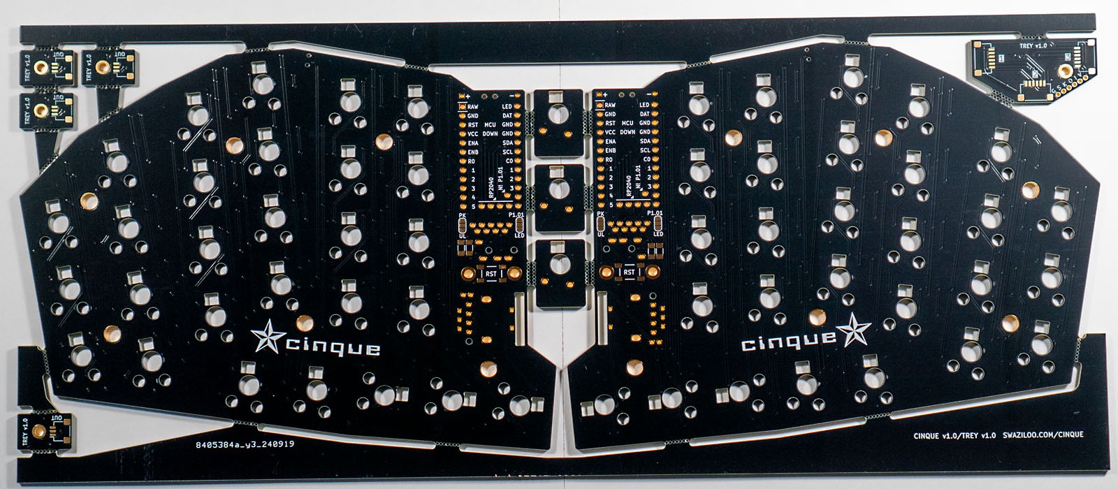
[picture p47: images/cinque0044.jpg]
cinque PCB top

## Keyboard Parts
| Item | Quantity | Detail |
|---|---|---|
| PCB | 1 | A single 1.6mm panel provides both halves of the keyboard and 8 small breakout boards for the trackball |
| Switch Plates | 2 | 1.2mm plates with a cutout matching the intended encoder. note that the current pcb panel includes one of each style |
| ProMicro | 2 | For wired QMK/RGB builds, [Tenstar Robot RP2040](https://www.aliexpress.us/item/3256806781060135.html) with the extra 5 pins at the bottom. For wireless/Nice!View the NRF52840 development board. I used (and the extra pins are aligned to) the [Tenstar Robot NRF52840](https://www.aliexpress.us/item/3256806085464792.html) from AliExpress. Other ProMicro boards should be viable. |
| Switches | 58 | Gateron KS-33 low-profile mechanical switches |
| Hotswap Sockets | 58 | Gateron KS-33 hotswap sockets |
| Diodes | 60 | 1N4148 SOD-123 (or equivalent) SMD diodes |
| Keycaps | 58 | MX stem low-profile or LDA |
| Per-key RGB | 58 | (optional) [SK-6812-E](https://www.digikey.com/en/products/detail/adafruit-industries-llc/4960/14302512) |
| Underglow RGB | 14 | (optional) [3535 SMD RGB](https://www.digikey.com/en/products/detail/inolux/IN-PI33TBTPRPGPB/9681238) |
| Encoders | 2 | (optional) EC11 (recommend 30 PPR 9.5mm height) with 13-16mm knob or Panasonic EVQWGD001 on either side |
| Displays | 2 | (optional) 0.91" I2C OLED or Nice!View |
| Reset Switches  | 2 | Two options supported [SM1207SM](https://www.digikey.com/en/products/detail/cit-relay-and-switch/CS1207SMF160/16607829) along the top edge/underside of the PCB and/or [SKQGABE010](https://www.digikey.com/en/products/detail/alps-alpine/SKQGABE010/19529161) between the mounts above the encoders |
| TRRS Jack | 2 | If using wired connection. Plus TRRS cable |
| Resistors | 4 | (If using split I2C) 1206 SMD 4.7kΩ pull-up resistors (not needed for Serial TRRS) |
| Power Switch | 2 | (For battery powered boards) [SPDT Slide Switch SMD](https://www.digikey.com/en/products/detail/alps-alpine/SSSS811101/19529062) |
| Battery | 2 | (For battery powered boards) 3.7v LiPo 110mAh 301230 or larger, depending on placement |
| Hardware | * | m2 inserts, screws, and standoffs vary depending on case and configuration. Use adhesive rubber feet to prevent sliding. |

## Trackball Parts
| Item | Quantity | Detail |
|---|---|---|
| PCB | 8 | 1.6mm breakout boards from keyboard |
| PMW3389 Module | 1 | [Joe's Sensors and Sundry](https://www.tindie.com/products/citizenjoe/pmw3389-motion-sensor/) |
| Switches | 3 | Gateron KS-33 low-profile mechanical switches |
| Diodes | 3 | 1N4148 SOD-123 (or equivalent) SMD diodes |
| Per-key RGB | 3 | (optional) [SK-6812-E](https://www.digikey.com/en/products/detail/adafruit-industries-llc/4960/14302512) |
| Underglow RGB | 4 | (optional) [3535 SMD RGB](https://www.digikey.com/en/products/detail/inolux/IN-PI33TBTPRPGPB/9681238) |
| JST SH 1.0 SMD Socket | 14 | 8x 3-pin horizontal, 3x 6-pin horizontal, 3x 6-pin vertical |
| JST SH 1.0 Cable | 7 | 4x 3-pin 10cm reverse, 3x 6-pin 10cm reverse |
| FPC 1.0 | 3 | 2x 12-pin SMD, 1x 10cm ribbon (same side) |
| SiO2 Bearings | 6 | 3x 2.5mm and 3x 3.0mm |
| Trackball | 1 | 44mm |
| Hardware | 6 | 1.7mm diameter, 4-6mm long screws, hot glue, small zip ties |

## Guidelines
Soldered jumpers:
- **PK&mdash;UL** determines whether the RGB signal sent to the trackball runs off the end of the per-key (28) set or after the underglow (35).
  - Only solder the jumper on the side that will drive the trackball RGB.
  - Not needed if not using the trackball with RGB.
  - Ensure that the configuration in `info.json` matches the physical setup you enable.
- **P1.01&mdash;LED** determines the CS pin if using the Nice!View display.
  - Note that if hacking a Nice!View with another MCU and RGB (LED) in use, any pin that can handle CS can be soldered to the P1.01 socket under the ProMicro.
- **SER&mdash;I2C** determines the TRRS communication mode (I2C is untested).
  - If using I2C you'll also need to solder 2x 1206 SMD 4.7kΩ pull-up resistors on the front of the boards.

| | |
|---|---|
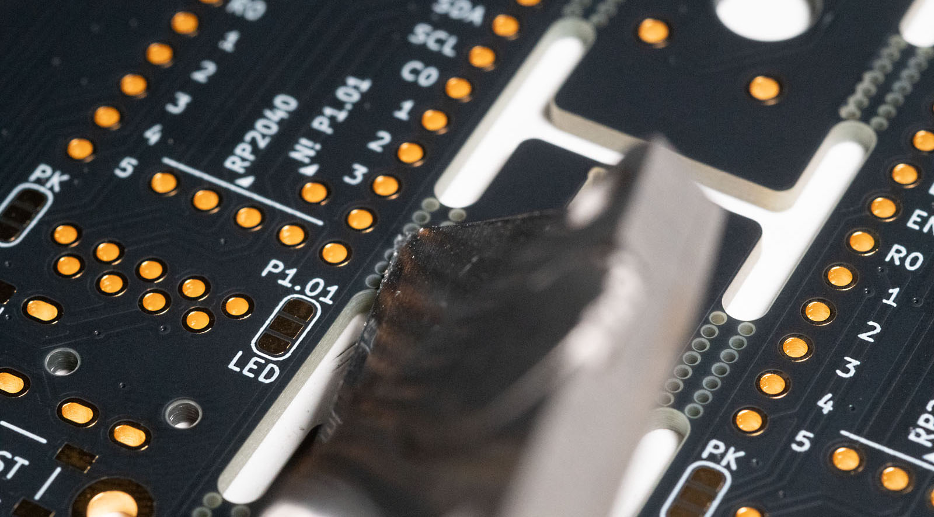
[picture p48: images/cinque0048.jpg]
scoring breakaway tabs
|  | *Be very careful separating the panel!* There are traces close to the edge. It is wise to score the mouse bites before breaking apart, particularly along the inside edge. |
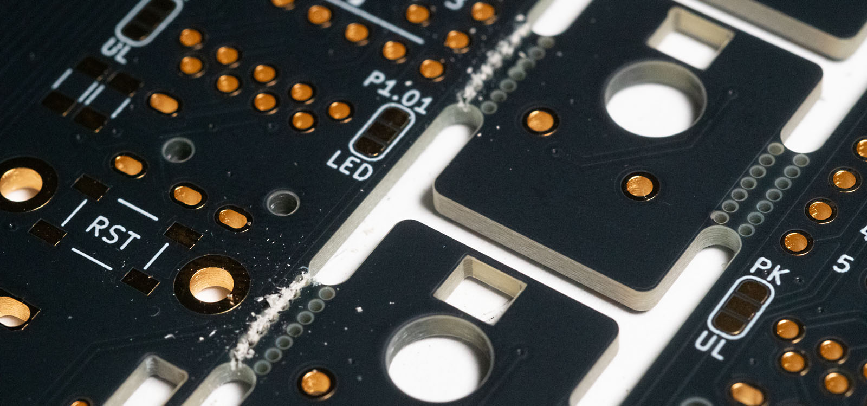
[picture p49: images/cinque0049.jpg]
scored tabs near traces
|  | Mouse bites scored with a box knife blade. |
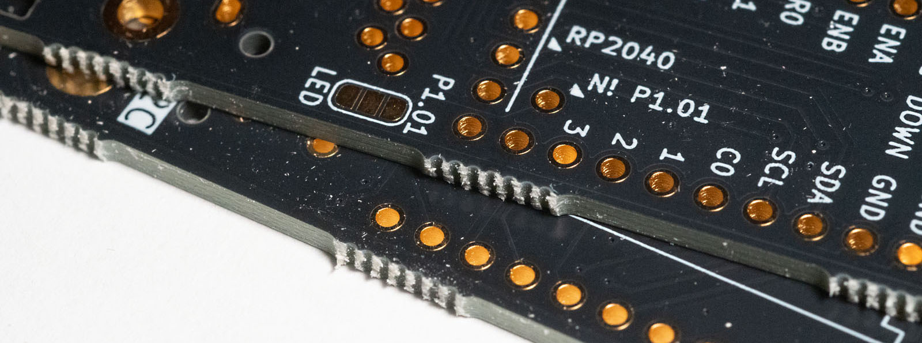
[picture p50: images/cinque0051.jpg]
separated board near traces
|  | Separated board will have jagged edges. Recommend cautious grinding with a sanding wheel on a dremel. |
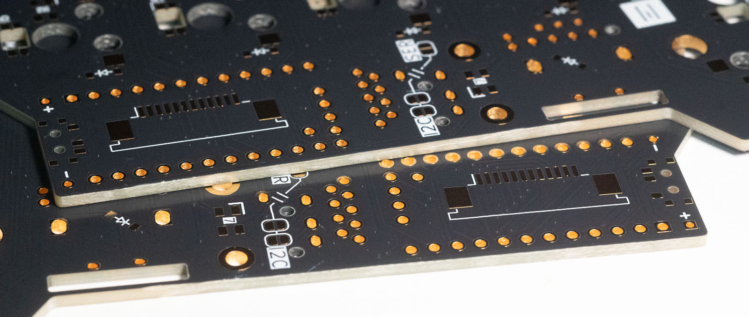
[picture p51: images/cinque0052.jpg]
sanded board near traces
|  | Board edge smoothed and ready for assembly. |
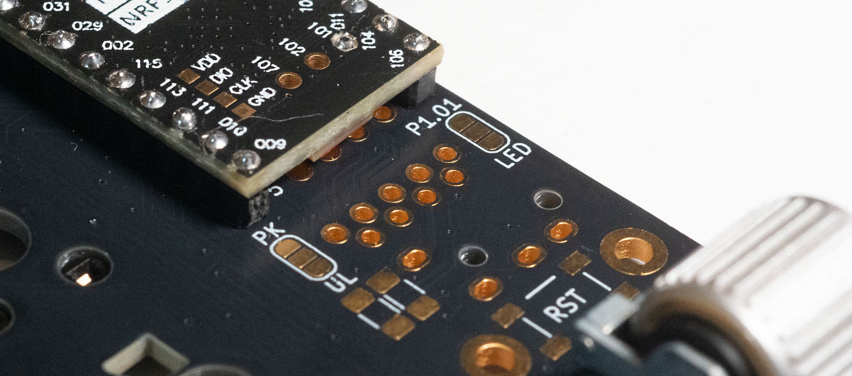
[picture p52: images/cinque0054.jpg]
board jumpers
|  | The board features soldered jumpers. For either top jumper, connect the center pad with one option.<br/><br/>Also note that I re-measured the slot for the Panasonic encoder. It's a snug, if accurate fit. You do not need to clip off the "feet"&mdash;in fact they help hold it in place, but you may need to shave a little off the back corner to help rock it into place. |
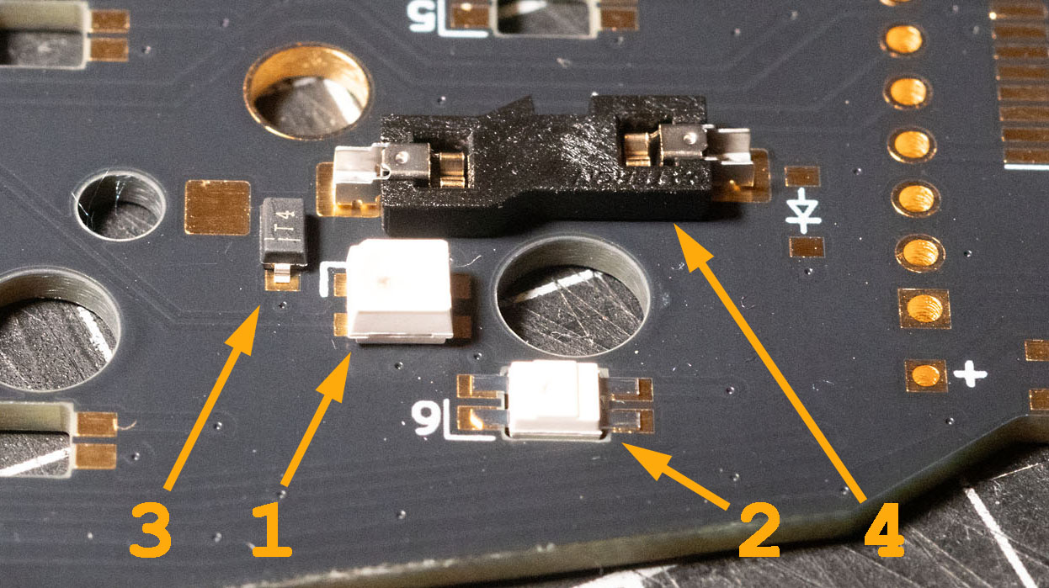
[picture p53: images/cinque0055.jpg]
|  | The density of this board can make hand soldering tricky in places. I recommend beginning with the 3535 underglow RGBs since it can be difficult to hand solder those short pads. |
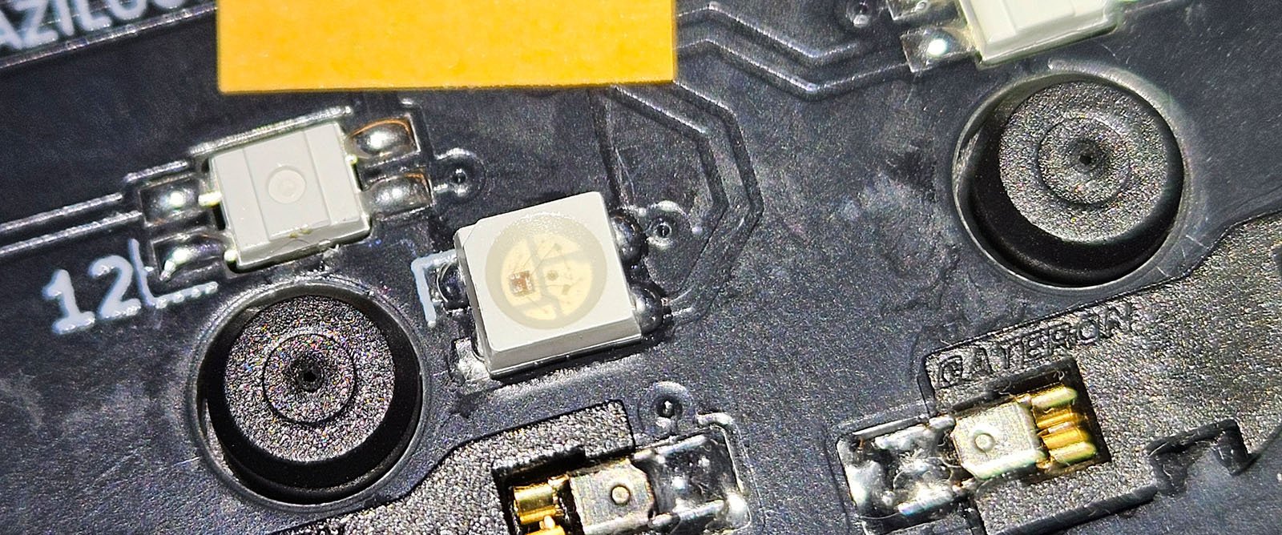
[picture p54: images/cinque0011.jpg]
failed solder on RGB
|  | For example, this underglow LED has a bad solder joint and needed to be reflowed. It was not the only one. |
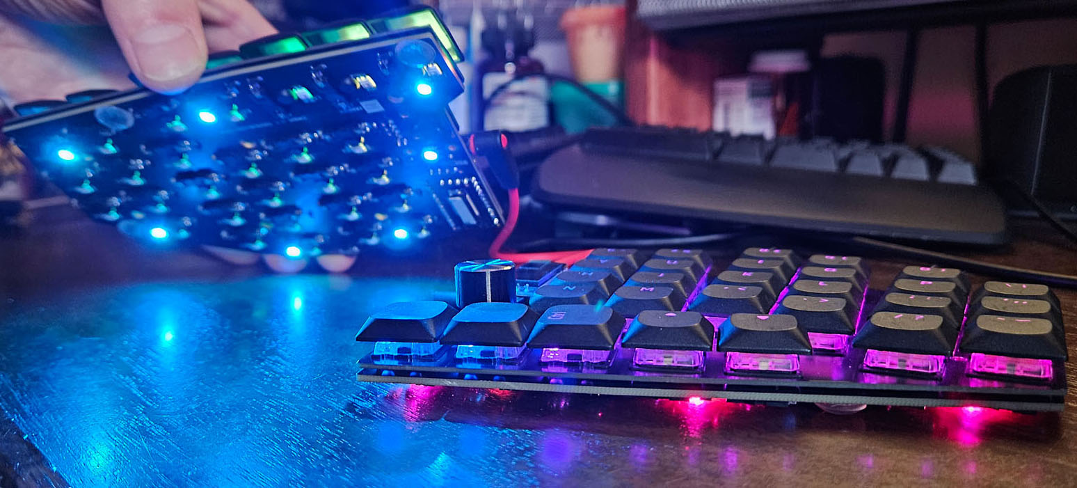
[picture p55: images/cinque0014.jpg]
|  | The underglow LEDs are definitely the crux when building this board. In a future update I will extend the pads to make soldering them easier. |
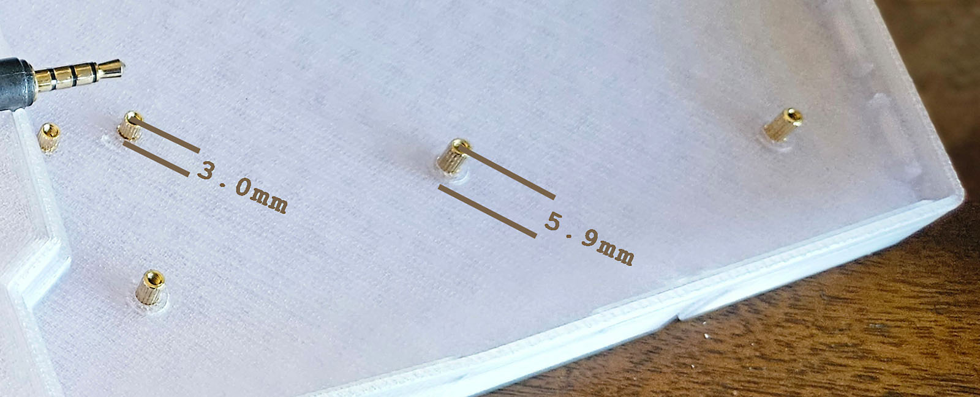
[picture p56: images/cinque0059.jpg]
|  | When using heat-melt inserts (m2, 3mm) and standoffs (3mm and 5mm), take care to ensure that the total height above the case is 5.9mm for all 6 through-hole mounts and 3.0mm for both direct/cover mounts. |
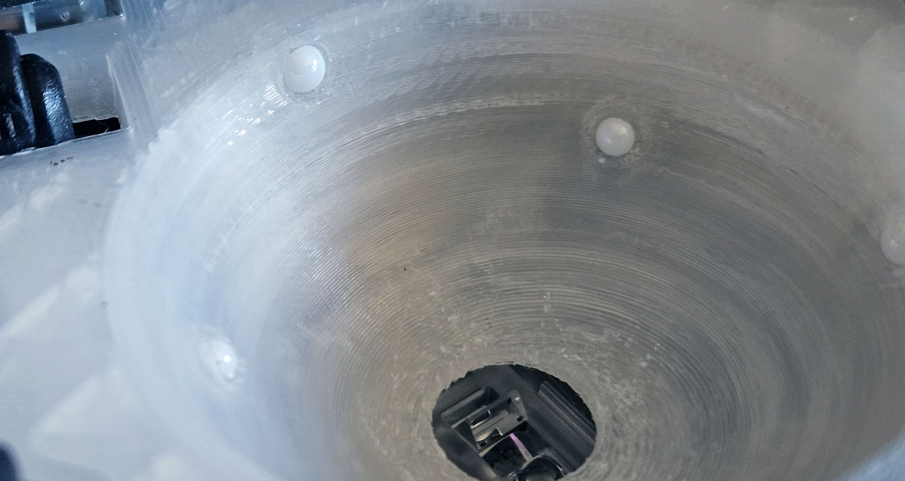
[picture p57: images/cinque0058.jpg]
trackball bearings
|  | The trackball bearings are fixed SiO2 spheres that you melt into the printed housing. Use a thick insert tool or similar object heated to 200c (400f) to gently press them into place while checking the clearance from the ball to the bottom mounting surface. It should be as close as possible to 2.0mm. Begin with the bottom three 2.5mm and get them perfect, then add the top 3.0mm and sink them until the ball just barely tips into them when pushed from the side. |
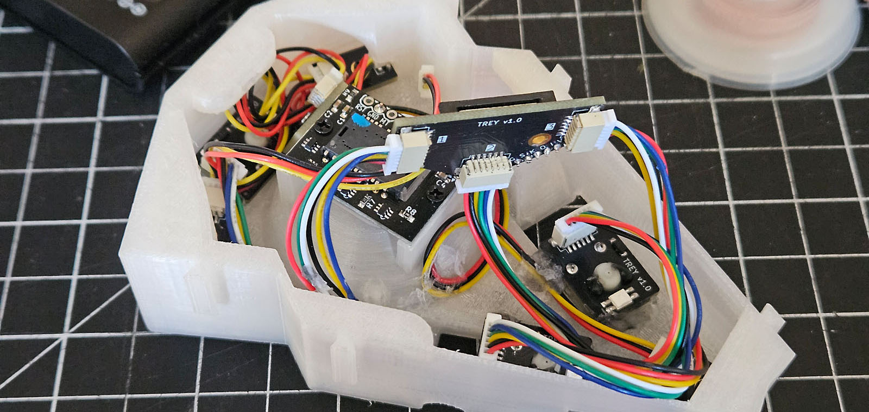
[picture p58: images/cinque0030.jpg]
trackball wiring
|  | When assembling the trackball breakout boards, take care to keep components from overhanging the edges. Test components before screwing or gluing them into the housing and be sure you're using "reversed" cables (pins are the same on both ends, not flipped). |
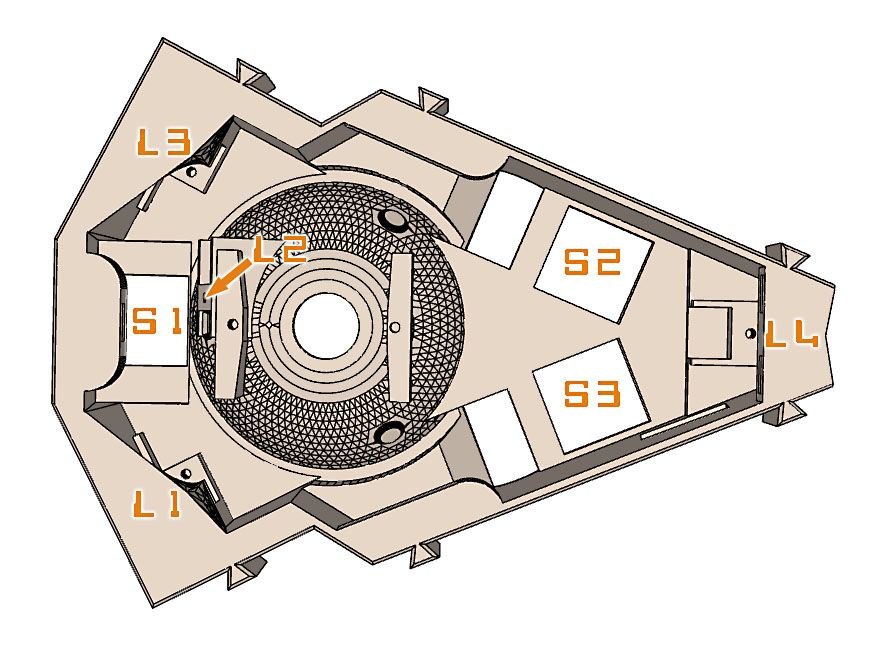
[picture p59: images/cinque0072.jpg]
trackball switch and led order
|  | Connect switches and LEDs to the connector board in the order shown here (from below). Connect the board "OUT" to the "IN" side of L1, and then string "OUT" to "IN" for L2-L4. L1, L3, and L4 face down (towards your desk). L2 can face either direction. |
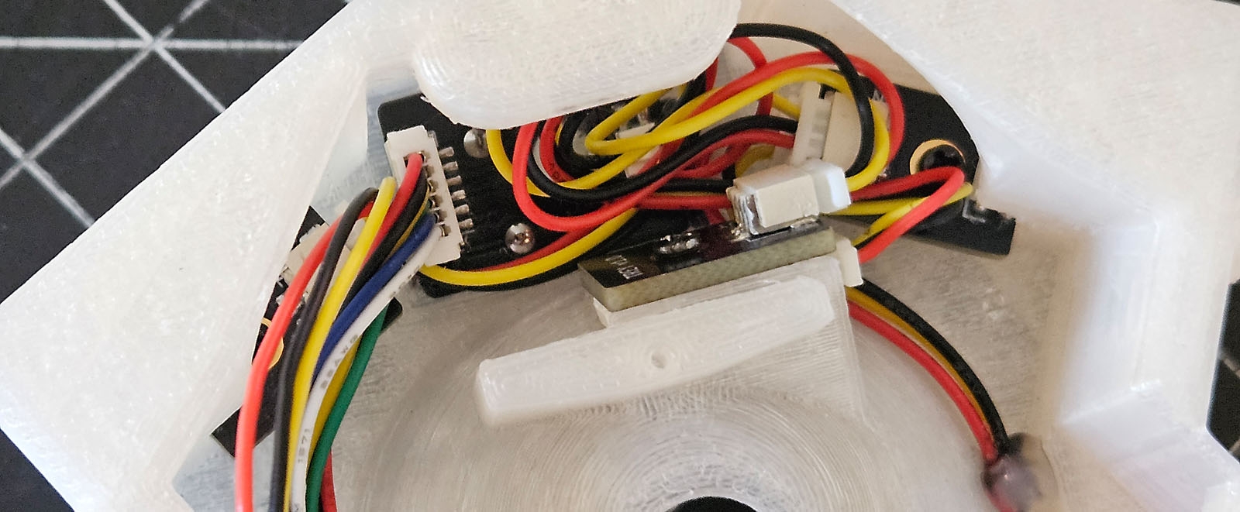
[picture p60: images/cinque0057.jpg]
trackball fitting
|  | Start with the switch plates. Use a dab of hot glue on two sides to secure them. The middle, front RGB can face up or down. |
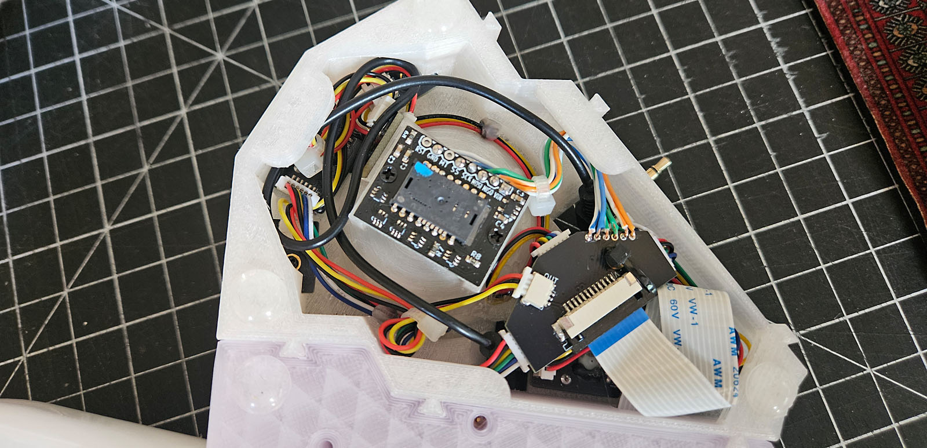
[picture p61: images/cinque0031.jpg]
trackball connected
|  | The wiring from the PMW3389 breakout to the connector board should be apparent. The "RST" and "MT" connections are unused. The FPC ribbon will be a little long. Recommend a thin, short TRRS cable that will wrap around the other components. |

If anything is unclear, please ask me to add clarification. 
I'll happily respond to any questions you have about building any of this.

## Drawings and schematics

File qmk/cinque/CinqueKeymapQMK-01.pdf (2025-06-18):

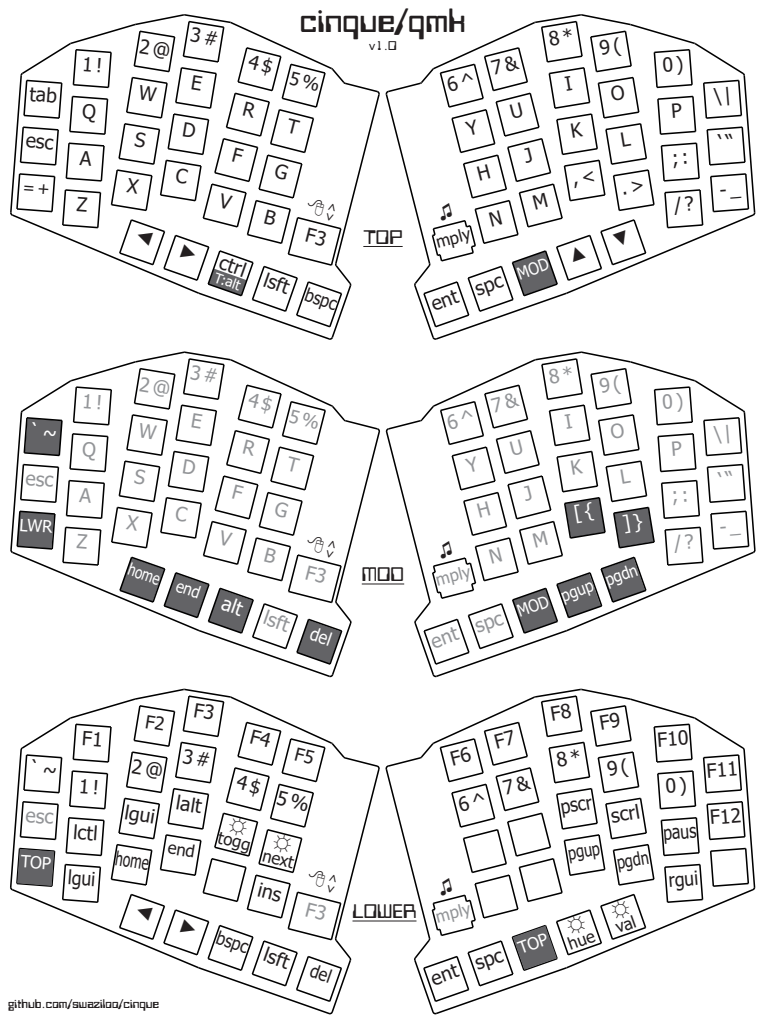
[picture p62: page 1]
tab; esc; ► ctrl; mply; LWR; home; lctl; lgui; lalt; end; togg next; ins; pscr; pgup; scrl; pgdn; paus; rgui; TOP; MOD; LOWER; cinque/qmk

ent spc MOD ▲ ▼

T:alt lsft bspc

ent spc MOD pgup pgdn

end alt lsft del

► bspc lsft del

ent spc TOP hue val

github.com/swaziloo/cinque

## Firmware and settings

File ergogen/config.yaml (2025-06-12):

  units:
    # Spacing Variables
    kx: 18.7 # width mx 19 choc 18
    ky: 18.7 # height mx 19 choc 17
  points:
    zones:
      matrix:
        key:
          padding: 1ky
          spread: 1kx
          tags:
            - key
            - matrix_key
        anchor:
          rotate: 0 
          shift: [100, -100]
        columns:
          outer:
            key.column_net: LC0
            key.mirror.column_net: RC0 
            rows:
              number:
                skip: true
              top.key:
                led_prev: LL_25
                led_next: LL_26
                mirror.led_prev: RL_25
                mirror.led_next: RL_26
              home.key:
                led_prev: LL_26
                led_next: LL_27
                mirror.led_prev: RL_26
                mirror.led_next: RL_27
              bottom.key:
                led_prev: LL_27
                led_next: LL_28
                mirror.led_prev: RL_27
                mirror.led_next: RL_28
          pinky:
            key.stagger: -5
            key.column_net: LC1
            key.mirror.column_net: RC1    
            rows:
              number.key:
                led_prev: LL_24
                led_next: LL_25
                mirror.led_prev: RL_24
                mirror.led_next: RL_25
              top.key:
                led_prev: LL_23
                led_next: LL_24
                mirror.led_prev: RL_23
                mirror.led_next: RL_24
              home.key:
                led_prev: LL_22
                led_next: LL_23
                mirror.led_prev: RL_22
                mirror.led_next: RL_23
              bottom.key:
                led_prev: LL_21
                led_next: LL_22
                mirror.led_prev: RL_21
                mirror.led_next: RL_22
          ring:
            key.spread: .95kx
            key.origin: [-11.85, -kx]
            key.stagger: 10
            key.splay: -5
            key.column_net: LC2
            key.mirror.column_net: RC2
            rows:
              number.key:
                led_prev: LL_16
                led_next: LL_17
                mirror.led_prev: RL_16
                mirror.led_next: RL_17
              top.key:
                led_prev: LL_17
                led_next: LL_18
                mirror.led_prev: RL_17
                mirror.led_next: RL_18
              home.key:
                led_prev: LL_18
                led_next: LL_19
                mirror.led_prev: RL_18
                mirror.led_next: RL_19
              bottom.key:
                led_prev: LL_19
                led_next: LL_20
                mirror.led_prev: RL_19
                mirror.led_next: RL_20
          middle:
            key.stagger: 7
            key.column_net: LC3
            key.mirror.column_net: RC3    
            rows:
              number.key:
                led_prev: LL_15
                led_next: LL_16
                mirror.led_prev: RL_15
                mirror.led_next: RL_16
              top.key:
                led_prev: LL_14
                led_next: LL_15
                mirror.led_prev: RL_14
                mirror.led_next: RL_15
              home.key:
                led_prev: LL_13
                led_next: LL_14
                mirror.led_prev: RL_13
                mirror.led_next: RL_14
              bottom.key:
                led_prev: LL_12
                led_next: LL_13
                mirror.led_prev: RL_12
                mirror.led_next: RL_13
          index:
            key.spread: 1.01kx
            key.stagger: -7
            key.splay: -5
            key.column_net: LC4
            key.mirror.column_net: RC4    
            rows:
              number.key:
                led_prev: LL_6
                led_next: LL_7
                mirror.led_prev: RL_6
                mirror.led_next: RL_7
              top.key:
                led_prev: LL_7
                led_next: LL_8
                mirror.led_prev: RL_7
                mirror.led_next: RL_8
              home.key:
                led_prev: LL_8
                led_next: LL_9
                mirror.led_prev: RL_8
                mirror.led_next: RL_9
              bottom.key:
                led_prev: LL_9
                led_next: LL_10
                mirror.led_prev: RL_9
                mirror.led_next: RL_10
          inner:
            key.stagger: -2
            key.column_net: LC5
            key.mirror.column_net: RC5 
            rows:
              number.key:
                led_prev: LL_5
                led_next: LL_6
                mirror.led_prev: RL_5
                mirror.led_next: RL_6
              top.key:
                led_prev: LL_4
                led_next: LL_5
                mirror.led_prev: RL_4
                mirror.led_next: RL_5
              home.key:
                led_prev: LL_3
                led_next: LL_4
                mirror.led_prev: RL_3
                mirror.led_next: RL_4
              bottom.key:
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

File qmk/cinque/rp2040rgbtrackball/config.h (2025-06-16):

#pragma once

#define RP2040_BOOTLOADER_DOUBLE_TAP_RESET 
#define RP2040_BOOTLOADER_DOUBLE_TAP_RESET_TIMEOUT 200U
#define RP2040_BOOTLOADER_DOUBLE_TAP_RESET_LED GP17

#undef I2C_DRIVER
#undef I2C1_SDA_PIN
#undef I2C1_SCL_PIN
#define I2C_DRIVER I2CD1
#define I2C1_SDA_PIN GP2
#define I2C1_SCL_PIN GP3

#define OLED_BRIGHTNESS 16
#define OLED_TIMEOUT 300000
#define OLED_UPDATE_INTERVAL 100

#undef SPI_DRIVER
#undef SPI_SCK_PIN
#undef SPI_MISO_PIN
#undef SPI_MOSI_PIN
#define SPI_DRIVER SPID1
#define SPI_SCK_PIN GP14
#define SPI_MISO_PIN GP12
#define SPI_MOSI_PIN GP15
#define PMW33XX_CS_PIN GP13

#define POINTING_DEVICE_TASK_THROTTLE_MS 10
#define PMW33XX_CPI 500 // default 2000
#define PMW33XX_LIFTOFF_DISTANCE 0x02 // default 0x02
//#define ROTATIONAL_TRANSFORM_ANGLE 30 // default 0
#define POINTING_DEVICE_INVERT_X

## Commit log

2025-06-13 Added KiCad PCB files and JLCPCB gerbers
    [cinque-1.1-switchplate.kicad_pcb]
2025-06-13 Added cinque 1.0 case files--FreeCAD and stl
    [cinque-1.0-case-battery-left.stl, cinque-1.0-case-battery-right.stl, cinque-1.0-case-battery.FCStd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]
2025-06-13 Add I2C instructions for TRRS
2025-06-13 Added Panasonic encoder detail
2025-06-18 Add trackball breakout plate ordering
2025-06-18 Add insert/standoff sizes
